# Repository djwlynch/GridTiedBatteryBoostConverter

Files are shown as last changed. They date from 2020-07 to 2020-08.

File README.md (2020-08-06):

# GridTiedBatteryBoostConverter

This is a project to build a device that will allow a 28 Cell 100AH LiFePo4 Battery Pack
to be connected to a generic MPPT Grid Tied Inverter via the solar DC input.
It will limit the power drawn from the battery pack to a maximum of 1000W.
This should allow a good base load for a typical 1st world house.
The LiFePo4 cell is 3.2V nominal voltage and 3.65V Max. 3.1V is fairly flat,so
this means the 28 cell battery pack voltage range should be 86.8V min 89.6V Nominal and 102.2V Max.
The majority of Grid tied inverters I have seen won't start until they get 150V DC from Pannels,
so this device will boost this voltage up to 160V.  It will include a current sense transformer and
isolating transformer to sample the house Voltage and current Draw, and thus be able to determine the
houses power consumption from the Grid.  It will be able to sense the power that it is supplying
to the Grid Tied inverter, and use this info to try to keep the house power from the Grid at about 0 Watts.
It will do this until it supplies a maximum of 1000W to the inverter, any higher than this and the grid
can supply it.  It will also have FETs for turning on and off a seperate charger.
The charger is 2000W 102.2V 20A. The CPU of the system is a Teensy_LC, with LCD, 3 buttons and a ESP_WROOM_02U
wifi module. The LCD is driven by an I2C bus the ESP has jumperable access to this bus also, and the I2C
bus is brought out to a header incase extra monitoring is required ie temperature or pressure etc.

The peak current mode control is based around the UCC2800 TI mosfet gate driver.

Warning I am not an electrical engineer and this may kill you / burn down your house,
all risks are your own.  I have not yet built this myself, but will update when I have.

<b>To install :</b>
change into your kicad projects directory and issue<br>
git clone https://github.com/djwlynch/GridTiedBatteryBoostConverter
Also in you kicad project directory issue the following<br>
git clone https://github.com/djwlynch/custom_kicad_library --recursive

the --recursive is important and it pulls down the required submodules for kicad librarys I have used,
namely teensy_library and teensy.pretty and digikey_kicad_library.

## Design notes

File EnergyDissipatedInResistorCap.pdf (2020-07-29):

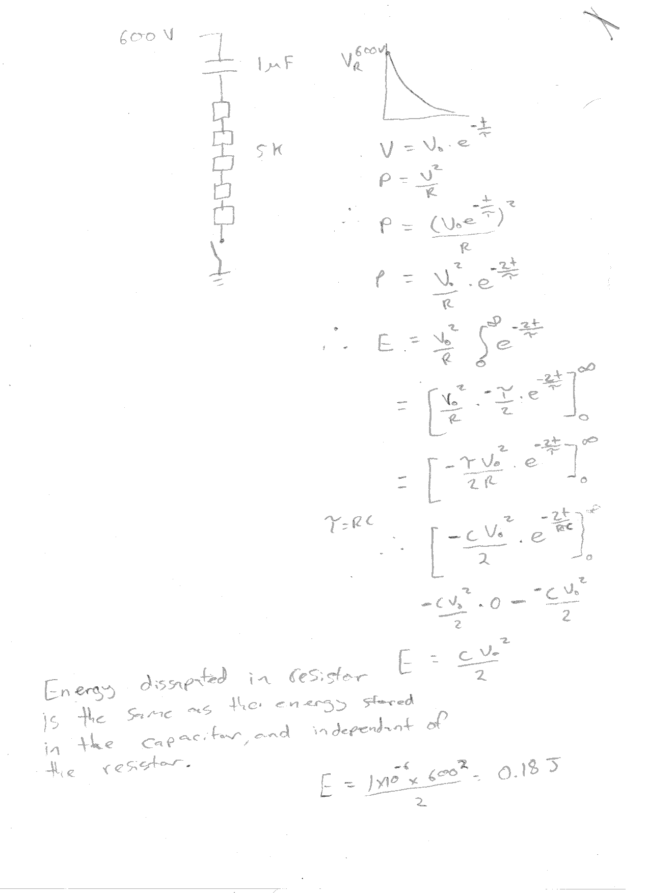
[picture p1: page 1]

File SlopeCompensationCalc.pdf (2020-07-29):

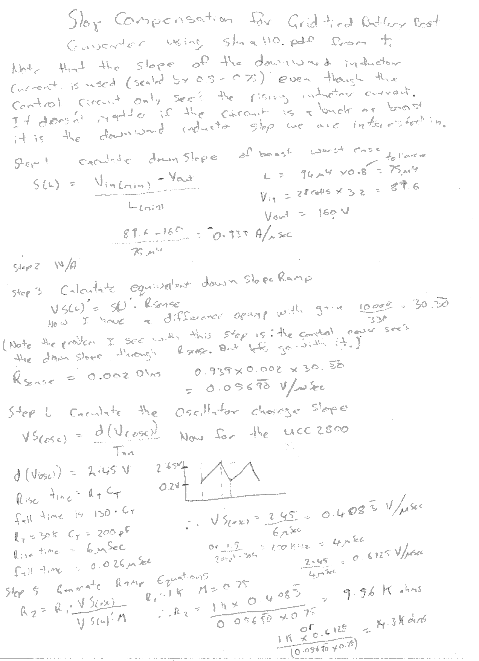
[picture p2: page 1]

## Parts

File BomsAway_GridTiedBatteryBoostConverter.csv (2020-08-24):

Refs | Value | Footprint | Quantity | MFR | MPN | SPR | SPN
SW202 | SW_Down | Buttons_Switches_ThroughHole_jl:SW_Tactile_SPST_Angled_FSM104 | 1 | TE Connectivity ALCOSWITCH Switches | FSM104 | digikey | 450-1127-ND
SW203 | SW_Enter | Buttons_Switches_ThroughHole_jl:SW_Tactile_SPST_Angled_FSM104 | 1 | TE Connectivity ALCOSWITCH Switches | FSM104 | digikey | 450-1127-ND
SW201 | SW_Up | Buttons_Switches_ThroughHole_jl:SW_Tactile_SPST_Angled_FSM104 | 1 | TE Connectivity ALCOSWITCH Switches | FSM104 | digikey | 450-1127-ND
C402;C403;C309;C312;C304;C109;C112;C107;C202;C203;C205 | 0.1uF X7R 25V 10% | Capacitor_SMD:C_0805_2012Metric_Pad1.15x1.40mm_HandSolder | 11 | Samsung | CL21B104KACNNNC | digikey | 1276-1099-1-ND
C302 | 0.47uF X7R 25V 10% | Capacitor_SMD:C_0805_2012Metric_Pad1.15x1.40mm_HandSolder | 1 | Samsung Electro-Mechanics | CL21B474KAFNNNE | digikey | 1276-1074-1-ND
Cint101 | 0.56uF X7R 16V 10% | Capacitor_SMD:C_0805_2012Metric_Pad1.15x1.40mm_HandSolder | 1 | KEMET | C0805C564K4RACTU | dikikey | 399-10074-1-ND
C105 | 100pF | Capacitor_SMD:C_0805_2012Metric_Pad1.15x1.40mm_HandSolder | 1 | KEMET | C0805C101JAGAC7800 | digikey | 399-15000-1-ND
C113 | 1nF | Capacitor_SMD:C_0805_2012Metric_Pad1.15x1.40mm_HandSolder | 1 | Yageo | CC0805KRX7R9BB102 | digikey | 311-1127-1-ND
C401;C313;C108;C114;C111;C106;C115;C201 | 1uF X7R 25V 10% | Capacitor_SMD:C_0805_2012Metric_Pad1.15x1.40mm_HandSolder | 8 | Wurth Elektronik | 885012207078 | digikey | 732-7672-1-ND
Ct101 | 200pF C0G 2% | Capacitor_SMD:C_0805_2012Metric_Pad1.15x1.40mm_HandSolder | 1 | AVX Corporation | 08051A201GAT2A | digikey | 478-10384-1-ND
Crolloff101 | 68pF C0G 5% | Capacitor_SMD:C_0805_2012Metric_Pad1.15x1.40mm_HandSolder | 1 | Wurth Elektronik | 885012007081 | digikey | 732-12227-1-ND
C110 | 6pF C0G | Capacitor_SMD:C_0805_2012Metric_Pad1.15x1.40mm_HandSolder | 1 | Yageo | CC0805CRNPO9BN6R0 | digikey | 311-4149-1-ND
C311;C310;C308;C307;C305;C301;C204 | 10uF X7R 25V 10% | Capacitor_SMD:C_1206_3216Metric_Pad1.42x1.75mm_HandSolder | 7 | Samsung Electro-Mechanics | CL31B106KAHNNNE | digikey | 1276-1804-1-ND
C306;C315 | 33uF X7R 16V 20% | Capacitor_SMD:C_1812_4532Metric_Pad1.30x3.40mm_HandSolder | 2 | TDK Corporation | C4532X7R1C336M250KC | digikey | 445-3924-1-ND
C303;C314 | 1uF X7R 250V 10% | Capacitor_SMD:C_2220_5650Metric_Pad1.97x5.40mm_HandSolder | 2 | TDK Corporation | C5750X7R2E105K230KA | digikey | 445-2304-1-ND
C101 | 220uF ALUM 200V 905 mOhm 20% | Capacitor_THT:CP_Radial_D22.0mm_P10.00mm_SnapIn | 1 | Cornell Dubilier Electronics (CDE) | SLP221M200A1P3 | digikey | 338-1478-ND
C103 | 470uF ALUM 400V 130mOhm 20% | Capacitor_THT:CP_Radial_D35.0mm_P10.00mm_SnapIn | 1 | KEMET | ELH477M400AT4AA | digikey | 399-6073-ND
C102 | 15uF PP 250VDC 3.9mOhm | Capacitors_ThroughHole_jl:C_Axial_44mm_24.5mm_P50mm | 1 | KEMET | C4GADUD5150AA1J | digikey | 399-13088-ND
C104 | 70uF PP Film 500V 2.1mOhm | Capacitors_ThroughHole_jl:C_RECT_4PIN_L42mm_W30mm_P37.5mm_P20.3mm | 1 | KEMET | C4AQLBW5700A3LK | digikey | 399-17006-ND
F301;F101 | Fuse Holder | Connect_jl:BellFuse_6.3mmX32mm_FC_102-22 | 2 | Bel Fuse Inc. | FC-102-22 | digikey | 507-1702-ND
U201 | LCD 2004A Right Angle Header 16 pin 2.54mm | Connect_jl:LCD2004_Pin_Header_Angled_1x16_Pitch2.54mm | 1 | Adam Tech | PH1RB-16-UA | digikey | 2057-PH1RB-16-UA-ND
J101 | Battery Connection | Connect_jl:PhoenixContact_1x4_P5mm | 1 | Phoenix Contact | 1935792 | digikey | 277-14426-ND
J103 | Solar Panels | Connect_jl:TerminalBlock_4way_P6.35mm_P9.5mm_Holes1.7mm | 1 | Phoenix Contact | 1017516 | digikey | 277-17506-ND
D301 | 1A 150V 0.7V SMA | Diode_SMD:D_SMA_Handsoldering | 1 | Diodes Incorporated | SBR1U150SA-13 | digikey | SBR1U150SA-13DICT-ND
D101 | 8A 200V 0.950V | Diodes_ThroughHole_jl:Diode_TO_220AC_Horizonal | 1 | Vishay Semiconductor Diodes Division | FES8DT-E3/45 | digikey | FES8DT-E3/45GI-ND
D501;D503;D502 | VS-20ETS12-M3 1200V 1V fwd@10A | Diodes_ThroughHole_jl:Diode_TO_220AC_Horizonal | 3 | Vishay Semiconductor Diodes Division | VS-20ETS12-M3 | digikey | VS-20ETS12-M3-ND
U203 | PCF8574ADWR | Housings_SOIC:SOIC-16W_7.5x10.3mm_Pitch1.27mm | 1 | Texas Instruments | PCF8574ADWR | digikey | 296-13105-1-ND
U102 | UCC2800DTR | Housings_SOIC:SOIC-8_3.9x4.9mm_Pitch1.27mm | 1 | Texas Instruments | UCC2800DTR | digikey | 296-39529-1-ND
L302;L303 | 15uH 730mA Sat | Inductors_jl:Inductor_1210_HandSoldering | 2 | Taiyo Yuden | CBC3225T150KR | digikey | 587-3066-1-ND
L301 | 150uH 610mA | Inductors_jl:Inductor_Bourns_PM3308 | 1 | Bourns Inc. | PM3308-151M-RC | digikey | PM3308-151M-RCCT-ND
L101;L102 | 47uH 31A Sat 6.38m Ohm | Inductors_jl:Inductor_Wurth_7443763540470 | 2 | Wurth Elektronik | 7443763540470 | digikey | 732-13644-ND
U101 | OPA2837IDGKR | Package_SO:VSSOP-8_3.0x3.0mm_P0.65mm | 1 | Texas Instruments | OPA2837IDGKR | digikey | 296-49464-1-ND
U402 | LMC7101BYM5-TR | Package_TO_SOT_SMD:SOT-23-5_HandSoldering | 1 | Microchip Technology | LMC7101BYM5-TR | digi-key | 576-2575-1-ND
U401 | MIC7211YM5-TR | Package_TO_SOT_SMD:SOT-23-5_HandSoldering | 1 | Microchip Technology | MIC7211YM5-TR | digi-key | 576-1318-1-ND
U304 | TLV70430DBVT | Package_TO_SOT_SMD:SOT-23-5_HandSoldering | 1 | Texas Instruments | TLV70430DBVT | digikey | 296-32419-1-ND
U303;U306 | TPS560200DBVR | Package_TO_SOT_SMD:SOT-23-5_HandSoldering | 2 | Texas Instruments | TPS560200DBVR | digikey | 296-38559-1-ND
D401;D402;D403;D103;D102;D104;D504 | BAT54S | Package_TO_SOT_SMD:SOT-23_Handsoldering | 7 | Toshiba Semiconductor and Storage | TBAT54S,LM | digikey | TBAT54SLMCT-ND
Q301;Q102 | BC847B-13-F | Package_TO_SOT_SMD:SOT-23_Handsoldering | 2 | Diodes Incorporated | BC847B-13-F | digikey | BC847B-13-FDICT-ND
Q302 | BC856B-13-F | Package_TO_SOT_SMD:SOT-23_Handsoldering | 1 | Diodes Incorporated | BC856B-13-F | digikey | BC856B-13-FDICT-ND
U305 | REF2925AIDBZT | Package_TO_SOT_SMD:SOT-23_Handsoldering | 1 | Texas Instruments | REF2925AIDBZT | digikey | 296-13482-1-ND
Q104;Q203 | SSM3J334R | Package_TO_SOT_SMD:SOT-23_Handsoldering | 2 | Toshiba Semiconductor and Storage | SSM3J334R,LF | digikey | SSM3J334RLFCT-ND
Q401;Q402;Q103;Q201;Q202 | SSM3K329R | Package_TO_SOT_SMD:SOT-23_Handsoldering | 5 | Toshiba Semiconductor and Storage | SSM3K329R,LF | digikey | SSM3K329RLFCT-ND
JP203 | BOOT_OPTION | Pin_Headers:Pin_Header_Straight_1x02_Pitch2.54mm | 1 | Sullins Connector Solutions | PREC002SAAN-RC | digikey | S1012EC-02-ND
JP202 | SCL_EN | Pin_Headers:Pin_Header_Straight_1x02_Pitch2.54mm | 1 | Sullins Connector Solutions | PREC002SAAN-RC | digikey | S1012EC-02-ND
JP201 | SDA_EN | Pin_Headers:Pin_Header_Straight_1x02_Pitch2.54mm | 1 | Sullins Connector Solutions | PREC002SAAN-RC | digikey | S1012EC-02-ND
J202 | Conn_01x03_Female | Pin_Headers:Pin_Header_Straight_1x03_Pitch2.54mm | 1 | Sullins Connector Solutions | PREC003SAAN-RC | digikey | S1012EC-03-ND
J203 | I2C_BUS | Pin_Headers:Pin_Header_Straight_1x04_Pitch2.54mm | 1 | Adam Tech | PH1-04-UA | digikey | 2057-PH1-04-UA-ND
RV201 | 5K | Potentiometers:Potentiometer_Trimmer_Bourns_3006P | 1 | Bourns Inc | 3006P-7-502LF | digikey | 3006P-7-502LF-ND
U204 | ESP-WROOM-02U | RF_Module_jl:MODULE_ESP-WROOM-02U | 1 | Espressif Systems | ESP-WROOM-02U | digikey | 1904-1022-1-ND
R101 | 0R Ohms | Resistor_SMD:R_0805_2012Metric_Pad1.15x1.40mm_HandSolder | 1 | Stackpole Electronics Inc | RMCF0805ZT0R00 | digikey | RMCF0805ZT0R00CT-ND
R412 | 1.15K 1% | Resistor_SMD:R_0805_2012Metric_Pad1.15x1.40mm_HandSolder | 1 | Yageo | RC0805FR-071K15L | digikey | 311-1.15KCRCT-ND
R407 | 1.27K 1% | Resistor_SMD:R_0805_2012Metric_Pad1.15x1.40mm_HandSolder | 1 | Yageo | RC0805FR-071K27L | digikey | 311-1.27KCRCT-ND
R104;Rint2;R122 | 1.5K 0.1% | Resistor_SMD:R_0805_2012Metric_Pad1.15x1.40mm_HandSolder | 3 | Panasonic Electronic Components | ERA-6AEB152V | digikey | P1.5KDACT-ND
R501;R502;R503;R504;R505;R205 | 100K 1% | Resistor_SMD:R_0805_2012Metric_Pad1.15x1.40mm_HandSolder | 6 | Yageo | RC0805FR-07100KL | digikey | 311-100KCRCT-ND
R206 | 100R 1% | Resistor_SMD:R_0805_2012Metric_Pad1.15x1.40mm_HandSolder | 1 | Yageo | RC0805FR-07100RL | digikey | 311-100CRCT-ND
R310;R121 | 105k 0.1% | Resistor_SMD:R_0805_2012Metric_Pad1.15x1.40mm_HandSolder | 2 | Panasonic Electronic Components | ERA-6AEB1053V | digikey | P105KDACT-ND
R110;R109;R117;R116 | 10K 0.1% | Resistor_SMD:R_0805_2012Metric_Pad1.15x1.40mm_HandSolder | 4 | Panasonic Electronic Components | ERA-6AEB103V | digikey | P10KDACT-ND
R113 | 10R 1% | Resistor_SMD:R_0805_2012Metric_Pad1.15x1.40mm_HandSolder | 1 | Yageo | RC0805FR-0710RL | digikey | 311-10.0CRCT-ND
R107;R207;R210;R209;R213 | 15K 1% | Resistor_SMD:R_0805_2012Metric_Pad1.15x1.40mm_HandSolder | 5 | TE Connectivity Passive Product | CRGCQ0805F15K | digikey | A129763CT-ND
R309 | 196K 0.1% | Resistor_SMD:R_0805_2012Metric_Pad1.15x1.40mm_HandSolder | 1 | Panasonic Electronic Components | ERA-6AEB1963V | digikey | P196KDACT-ND
R402;Rint1;R105 | 1K 0.1% | Resistor_SMD:R_0805_2012Metric_Pad1.15x1.40mm_HandSolder | 3 | Panasonic Electronic Components | ERA-6AEB102V | digikey | P1.0KDACT-ND
R405;R408;R406;R413;R409;R312;R301;R106;R108;R506;R201;R202;R203;R204 | 1K 1% | Resistor_SMD:R_0805_2012Metric_Pad1.15x1.40mm_HandSolder | 14 | Yageo | RC0805FR-071KL | digikey | 311-1.00KCRCT-ND
R410;R115 | 1M 1% | Resistor_SMD:R_0805_2012Metric_Pad1.15x1.40mm_HandSolder | 2 | Yageo | RC0805FR-071ML | digikey | 311-1.00MCRCT-ND
R311;R304 | 20K 0.1% | Resistor_SMD:R_0805_2012Metric_Pad1.15x1.40mm_HandSolder | 2 | Panasonic Electronic Components | ERA-6AEB203V | digikey | P20KDACT-ND
R308 | 226k 0.1% | Resistor_SMD:R_0805_2012Metric_Pad1.15x1.40mm_HandSolder | 1 | Panasonic Electronic Components | ERA-6AEB2263V | digikey | P226KDACT-ND
R403 | 240 0.1% | Resistor_SMD:R_0805_2012Metric_Pad1.15x1.40mm_HandSolder | 1 | Panasonic Electronic Components | ERA-6AEB241V | digikey | P240DACT-ND
Rt101 | 30K 0.1% | Resistor_SMD:R_0805_2012Metric_Pad1.15x1.40mm_HandSolder | 1 | Panasonic Electronic Components | ERA-6AEB303V | digikey | P30KDACT-ND
R111;R112;R118;R119 | 330R 0.1% | Resistor_SMD:R_0805_2012Metric_Pad1.15x1.40mm_HandSolder | 4 | Panasonic Electronic Components | ERA-6AEB331V | digikey | P330DACT-ND
R302 | 330R 1% | Resistor_SMD:R_0805_2012Metric_Pad1.15x1.40mm_HandSolder | 1 | TE Connectivity Passive Product | CRGCQ0805F330R | digikey | A129743CT-ND
R404 | 41.2 0.1% | Resistor_SMD:R_0805_2012Metric_Pad1.15x1.40mm_HandSolder | 1 | TE Connectivity Passive Product | 8-1625868-6 | digikey | A110410CT-ND
R211;R212;R208 | 4K7 1% | Resistor_SMD:R_0805_2012Metric_Pad1.15x1.40mm_HandSolder | 3 | Yageo | RC0805FR-074K7L | digikey | 311-4.70KCRCT-ND
R401 | 5.9K 0 .1% | Resistor_SMD:R_0805_2012Metric_Pad1.15x1.40mm_HandSolder | 1 | Panasonic Electronic Components | ERA-6AEB5901V | digikey | P5.9KDACT-ND
R303 | 61.9K 0.1% | Resistor_SMD:R_0805_2012Metric_Pad1.15x1.40mm_HandSolder | 1 | Panasonic Electronic Components | ERA-6AEB6192V | digikey | P61.9KDACT-ND
R103 | 75K 0.1% | Resistor_SMD:R_0805_2012Metric_Pad1.15x1.40mm_HandSolder | 1 | Panasonic Electronic Components | ERJ-PB6B7502V | digikey | P20808CT-ND
R102 | 82K 0.1% | Resistor_SMD:R_0805_2012Metric_Pad1.15x1.40mm_HandSolder | 1 | Panasonic Electronic Components | ERA-6AEB823V | digikey | P82KDACT-ND
R114;R120 | 2 mOhm Thick Film 1% 1W | Resistor_SMD:R_1210_3225Metric_Pad1.42x2.65mm_HandSolder | 2 | Rohm Semiconductor | PMR25HZPFV2L00 | digikey | RHM.002APCT-ND
U301 | FDA217 | SMD_Packages:DIP-8_SMD | 1 | IXYS Integrated Circuits Division | FDA217S | digikey | CLA408-ND
TP301 | TP +0.8V | TestPoint:TestPoint_Pad_3.0x3.0mm | 1 | - | - | - | -
TP304 | TP +11.0V | TestPoint:TestPoint_Pad_3.0x3.0mm | 1 | - | - | - | -
TP305 | TP +2.5V | TestPoint:TestPoint_Pad_3.0x3.0mm | 1 | - | - | - | -
TP307 | TP +3.0V | TestPoint:TestPoint_Pad_3.0x3.0mm | 1 | - | - | - | -
TP302;TP202 | TP +3.3V | TestPoint:TestPoint_Pad_3.0x3.0mm | 2 | - | - | - | -
TP303 | TP +5V | TestPoint:TestPoint_Pad_3.0x3.0mm | 1 | - | - | - | -
TP401 | TP 1.25V | TestPoint:TestPoint_Pad_3.0x3.0mm | 1 | - | - | - | -
TP403 | TP 1.395V | TestPoint:TestPoint_Pad_3.0x3.0mm | 1 | - | - | - | -
TP101 | TP 2.5V | TestPoint:TestPoint_Pad_3.0x3.0mm | 1 | - | - | - | -
TP203 | TP_Boost_On | TestPoint:TestPoint_Pad_3.0x3.0mm | 1 | - | - | - | -
TP306 | TP_Charger_On | TestPoint:TestPoint_Pad_3.0x3.0mm | 1 | - | - | - | -
TP103 | TP_DAC | TestPoint:TestPoint_Pad_3.0x3.0mm | 1 | - | - | - | -
TP201 | TP_LCD_On | TestPoint:TestPoint_Pad_3.0x3.0mm | 1 | - | - | - | -
TP402 | TP_Peak_Current | TestPoint:TestPoint_Pad_3.0x3.0mm | 1 | - | - | - | -
TP501 | TP_Solar_Voltage | TestPoint:TestPoint_Pad_3.0x3.0mm | 1 | - | - | - | -
TP102 | TP_UCC_5V_REF | TestPoint:TestPoint_Pad_3.0x3.0mm | 1 | - | - | - | -
TR401 | FS-10-110-C2 | Transformers_ThroughHole_jl:FS10-110-C2 | 1 | Triad Magnetics | FS10-110-C2 | digikey | 237-1578-ND
Q101 | IXFP36N20X3 | Transistors_ThroughHole_jl:TO-220_Horizontal_Offset_Drain | 1 | IXYS | IXFP36N20X3 | digikey | IXFP36N20X3-ND
Q305;Q306 | IRFP4321PBF | Transistors_ThroughHole_jl:TO-247-3_Horizontal_TabDown | 2 | Infineon Technologies | IRFP4321PBF | digikey | IRFP4321PBF-ND
J401;J402 | Screw_Terminal_01x02 | digikey-footprints:Term_Block_1x2_P5mm | 2 | Phoenix Contact | 1792863 | digikey | 277-2518-ND
U302 | LTC7138EMSE-PBF | ltc7138:LTC7138EMSE-PBF | 1 | Linear Technology/Analog Devices | LTC7138EMSE#PBF | digikey | LTC7138EMSE#PBF-ND
U202 | Teensy-LC | teensy:Teensy30_31_32_LC | 1 | SparkFun Electronics | DEV-13305 | digikey | 1568-1233-ND

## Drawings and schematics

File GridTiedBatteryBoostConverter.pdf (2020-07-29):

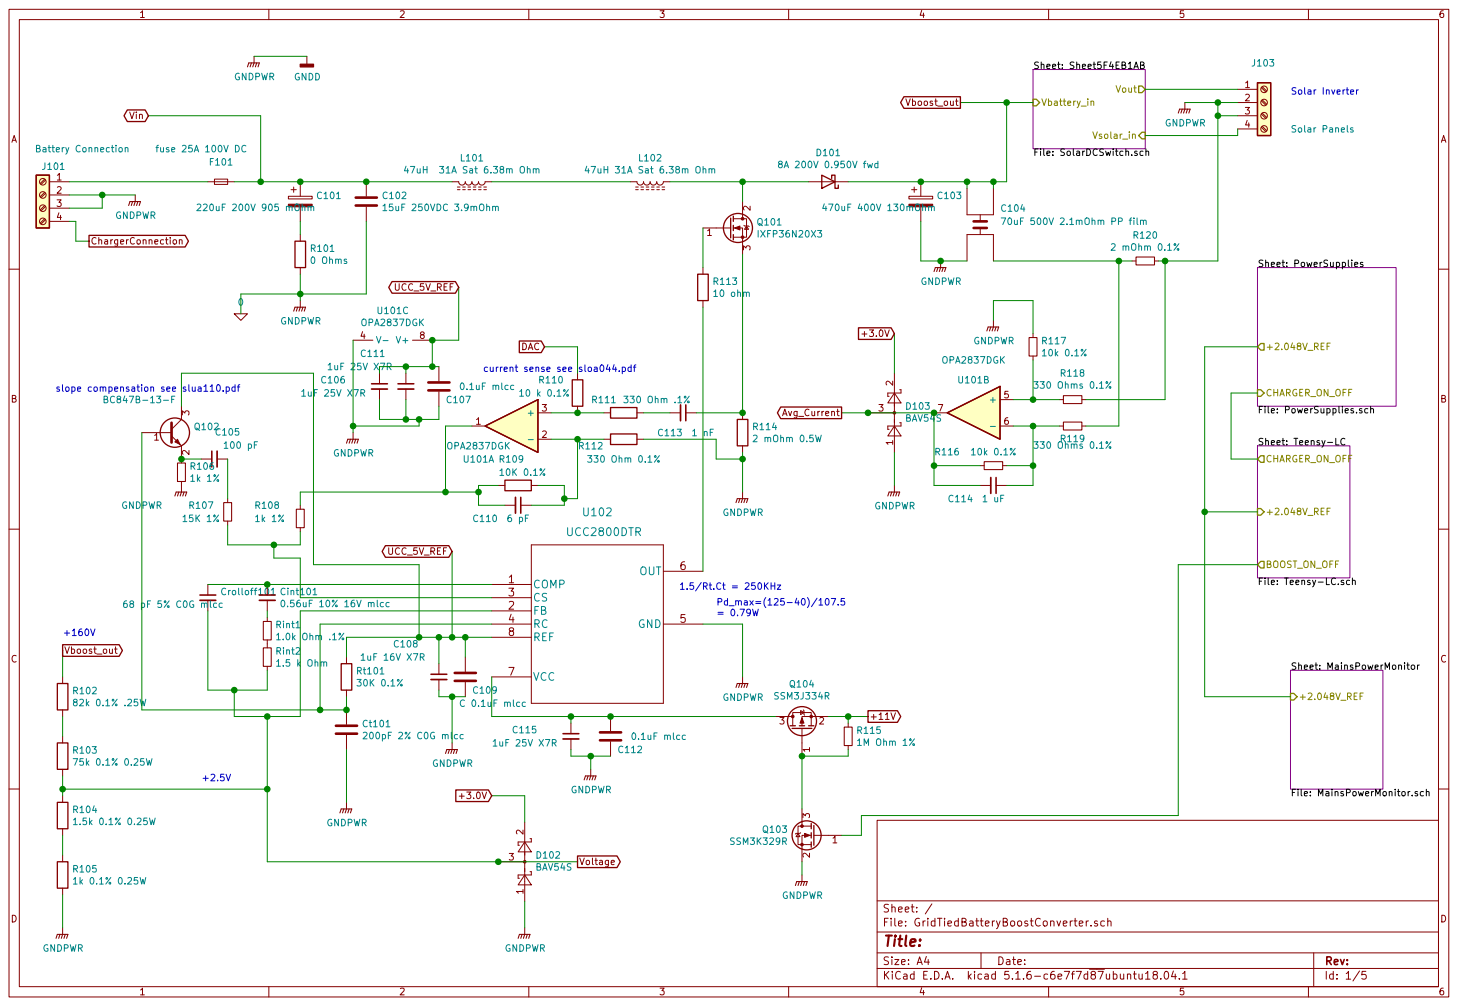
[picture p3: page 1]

File: SolarDCSwitch.sch Vsolar_in Vout Vbattery_in R112
IXFP36N20X3 GNDPWR

current sense see sloa044.pdf +160V

Sheet: Teensy-LC
File: Teensy-LC.sch CHARGER_ON_OFF BOOST_ON_OFF

File: GridTiedBatteryBoostConverter.sch Sheet: /
Id: 1/5 Title:

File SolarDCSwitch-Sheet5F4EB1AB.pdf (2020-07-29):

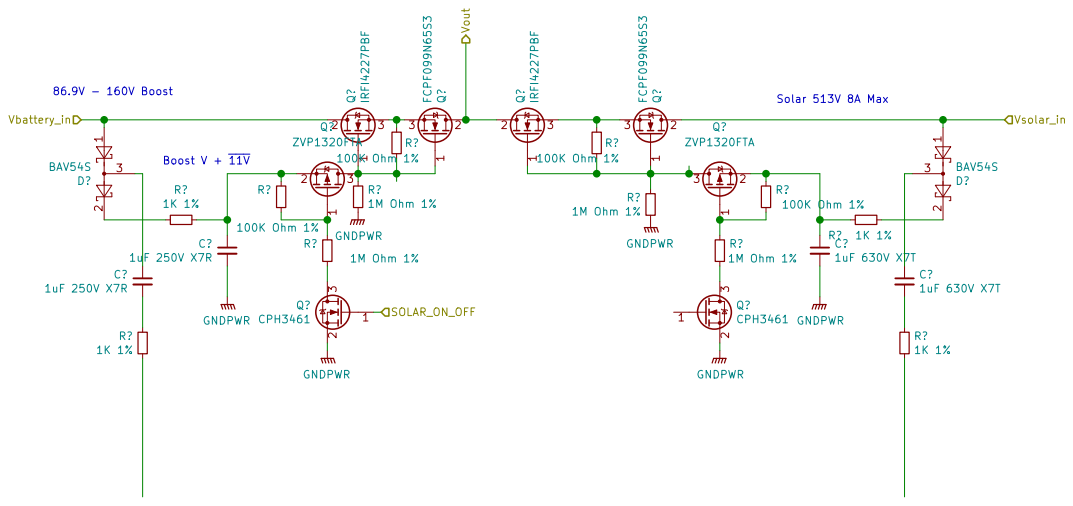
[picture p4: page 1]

Id: 5/5 Title: Battery / Solar Panel to Inverter Multiplexer File: SolarDCSwitch.sch Sheet: /Sheet5F4EB1AB/ John Lynch

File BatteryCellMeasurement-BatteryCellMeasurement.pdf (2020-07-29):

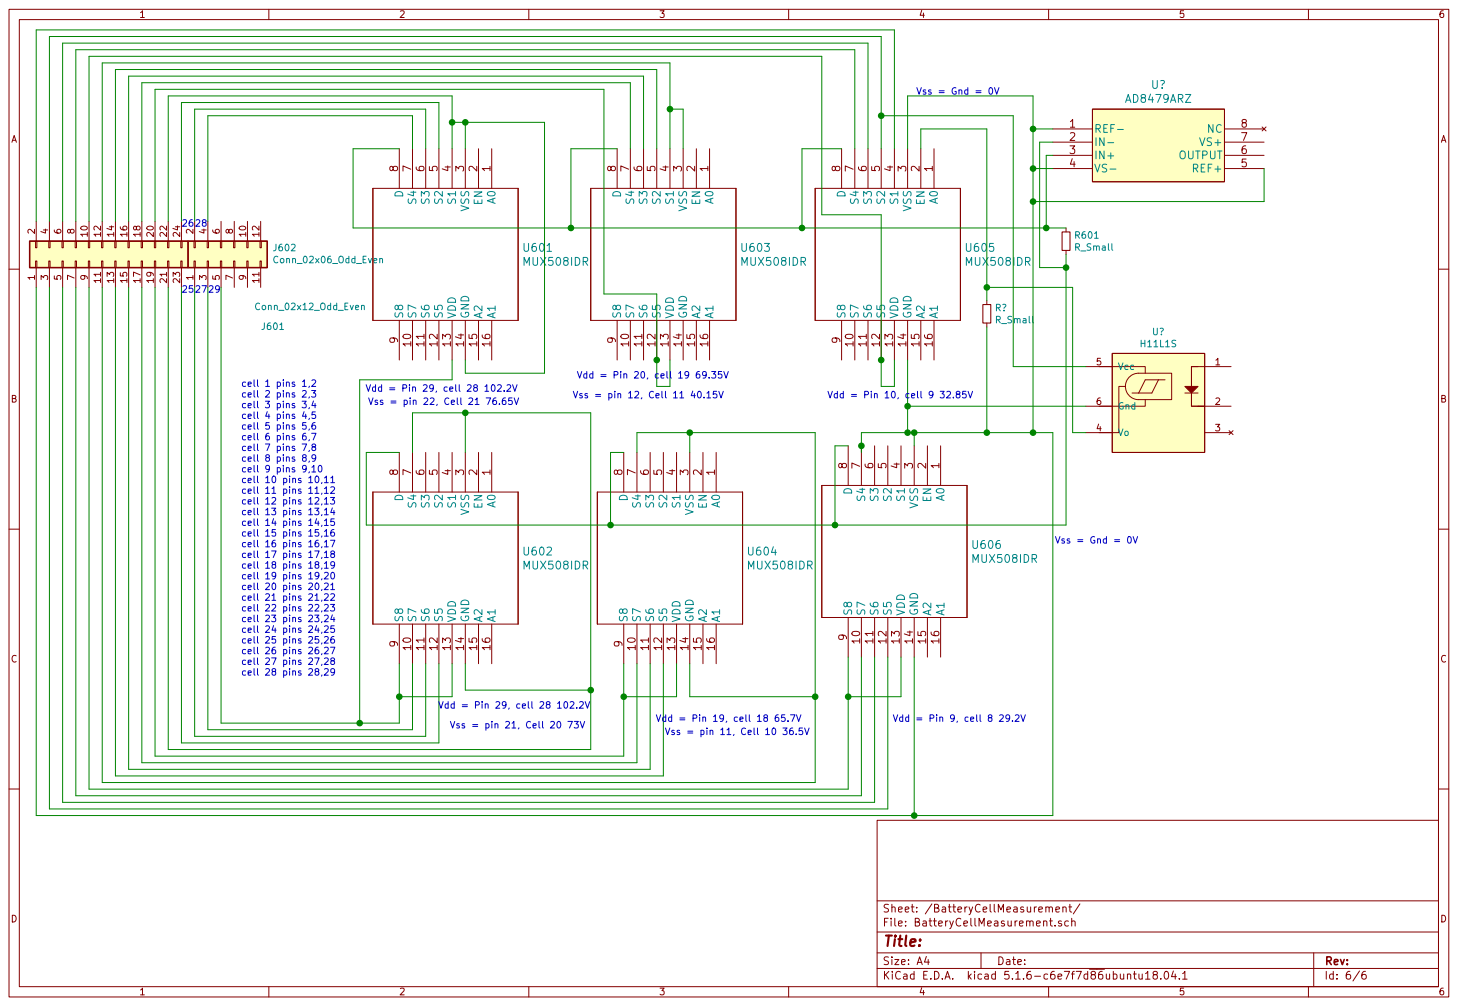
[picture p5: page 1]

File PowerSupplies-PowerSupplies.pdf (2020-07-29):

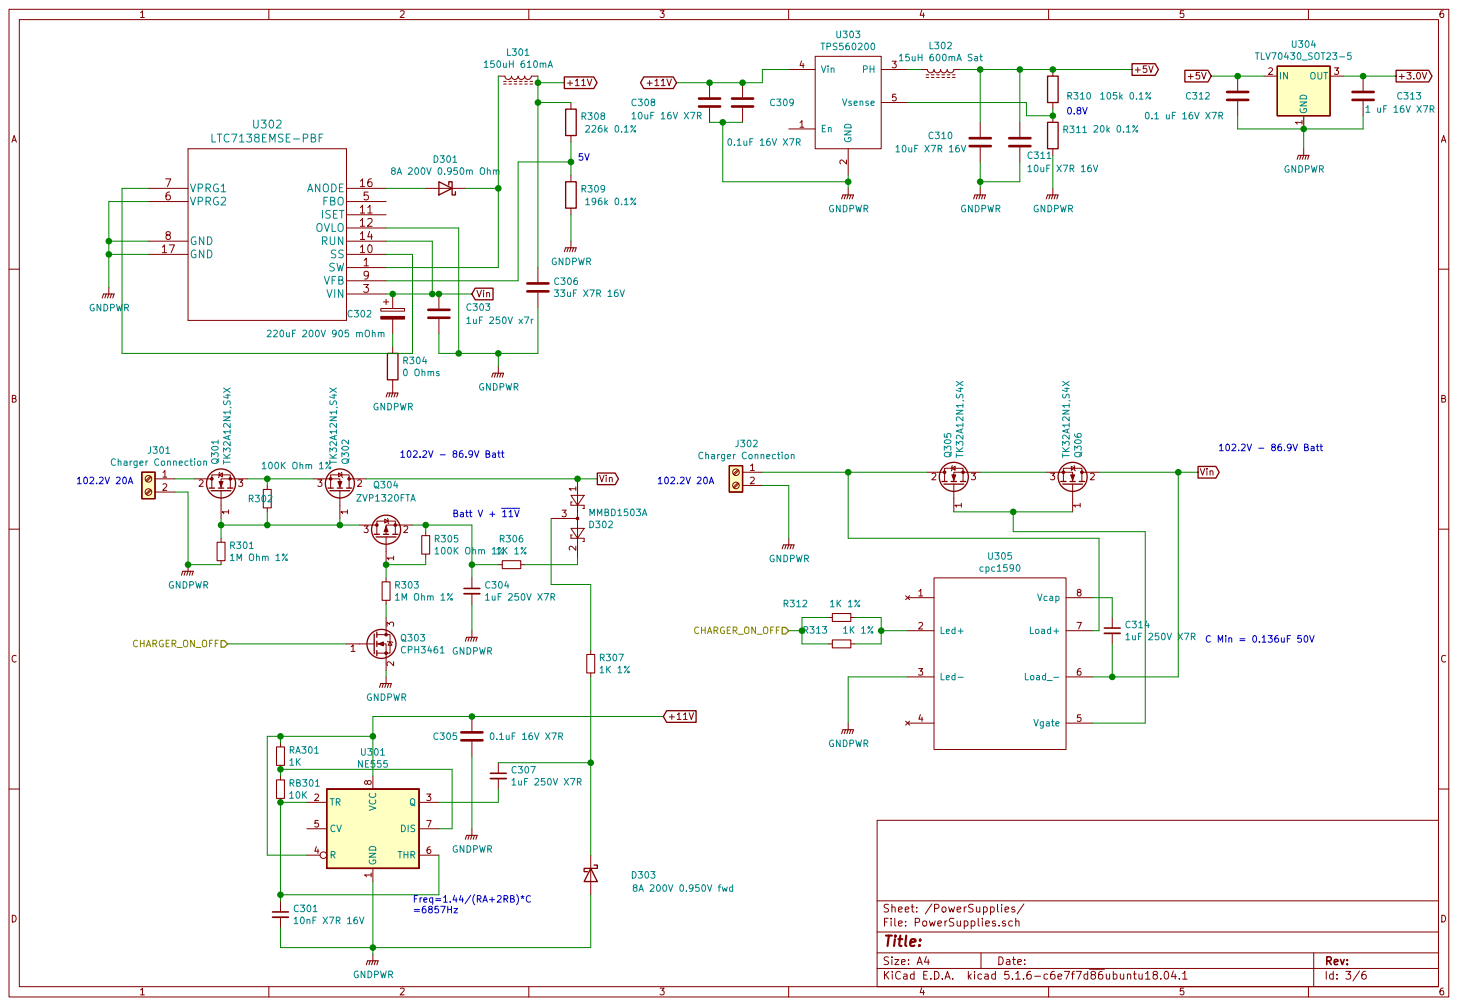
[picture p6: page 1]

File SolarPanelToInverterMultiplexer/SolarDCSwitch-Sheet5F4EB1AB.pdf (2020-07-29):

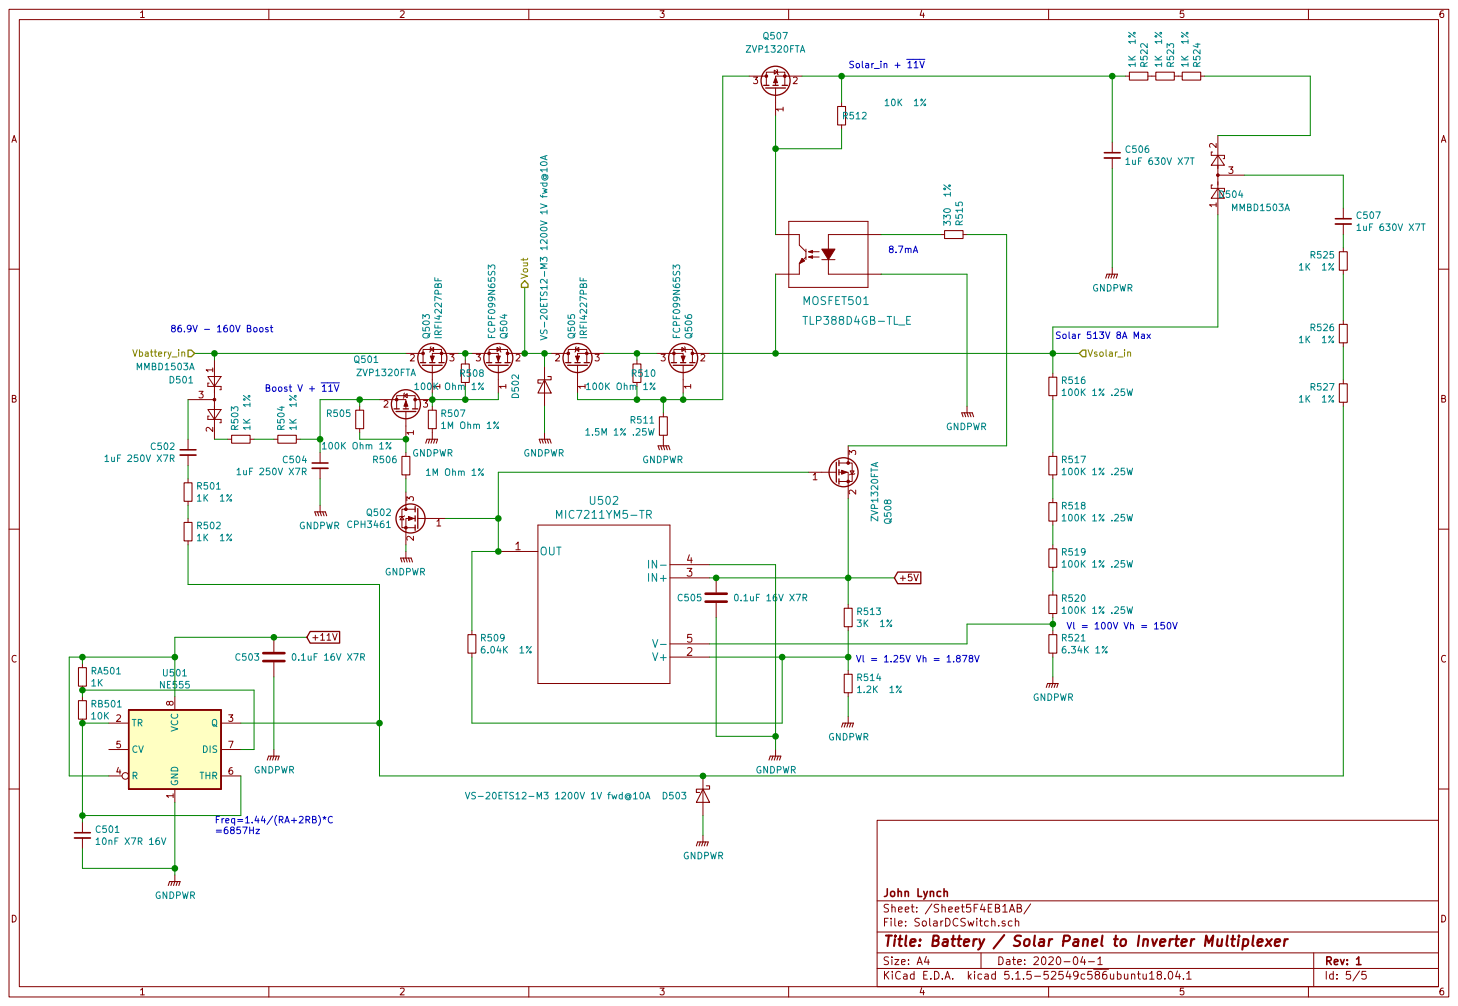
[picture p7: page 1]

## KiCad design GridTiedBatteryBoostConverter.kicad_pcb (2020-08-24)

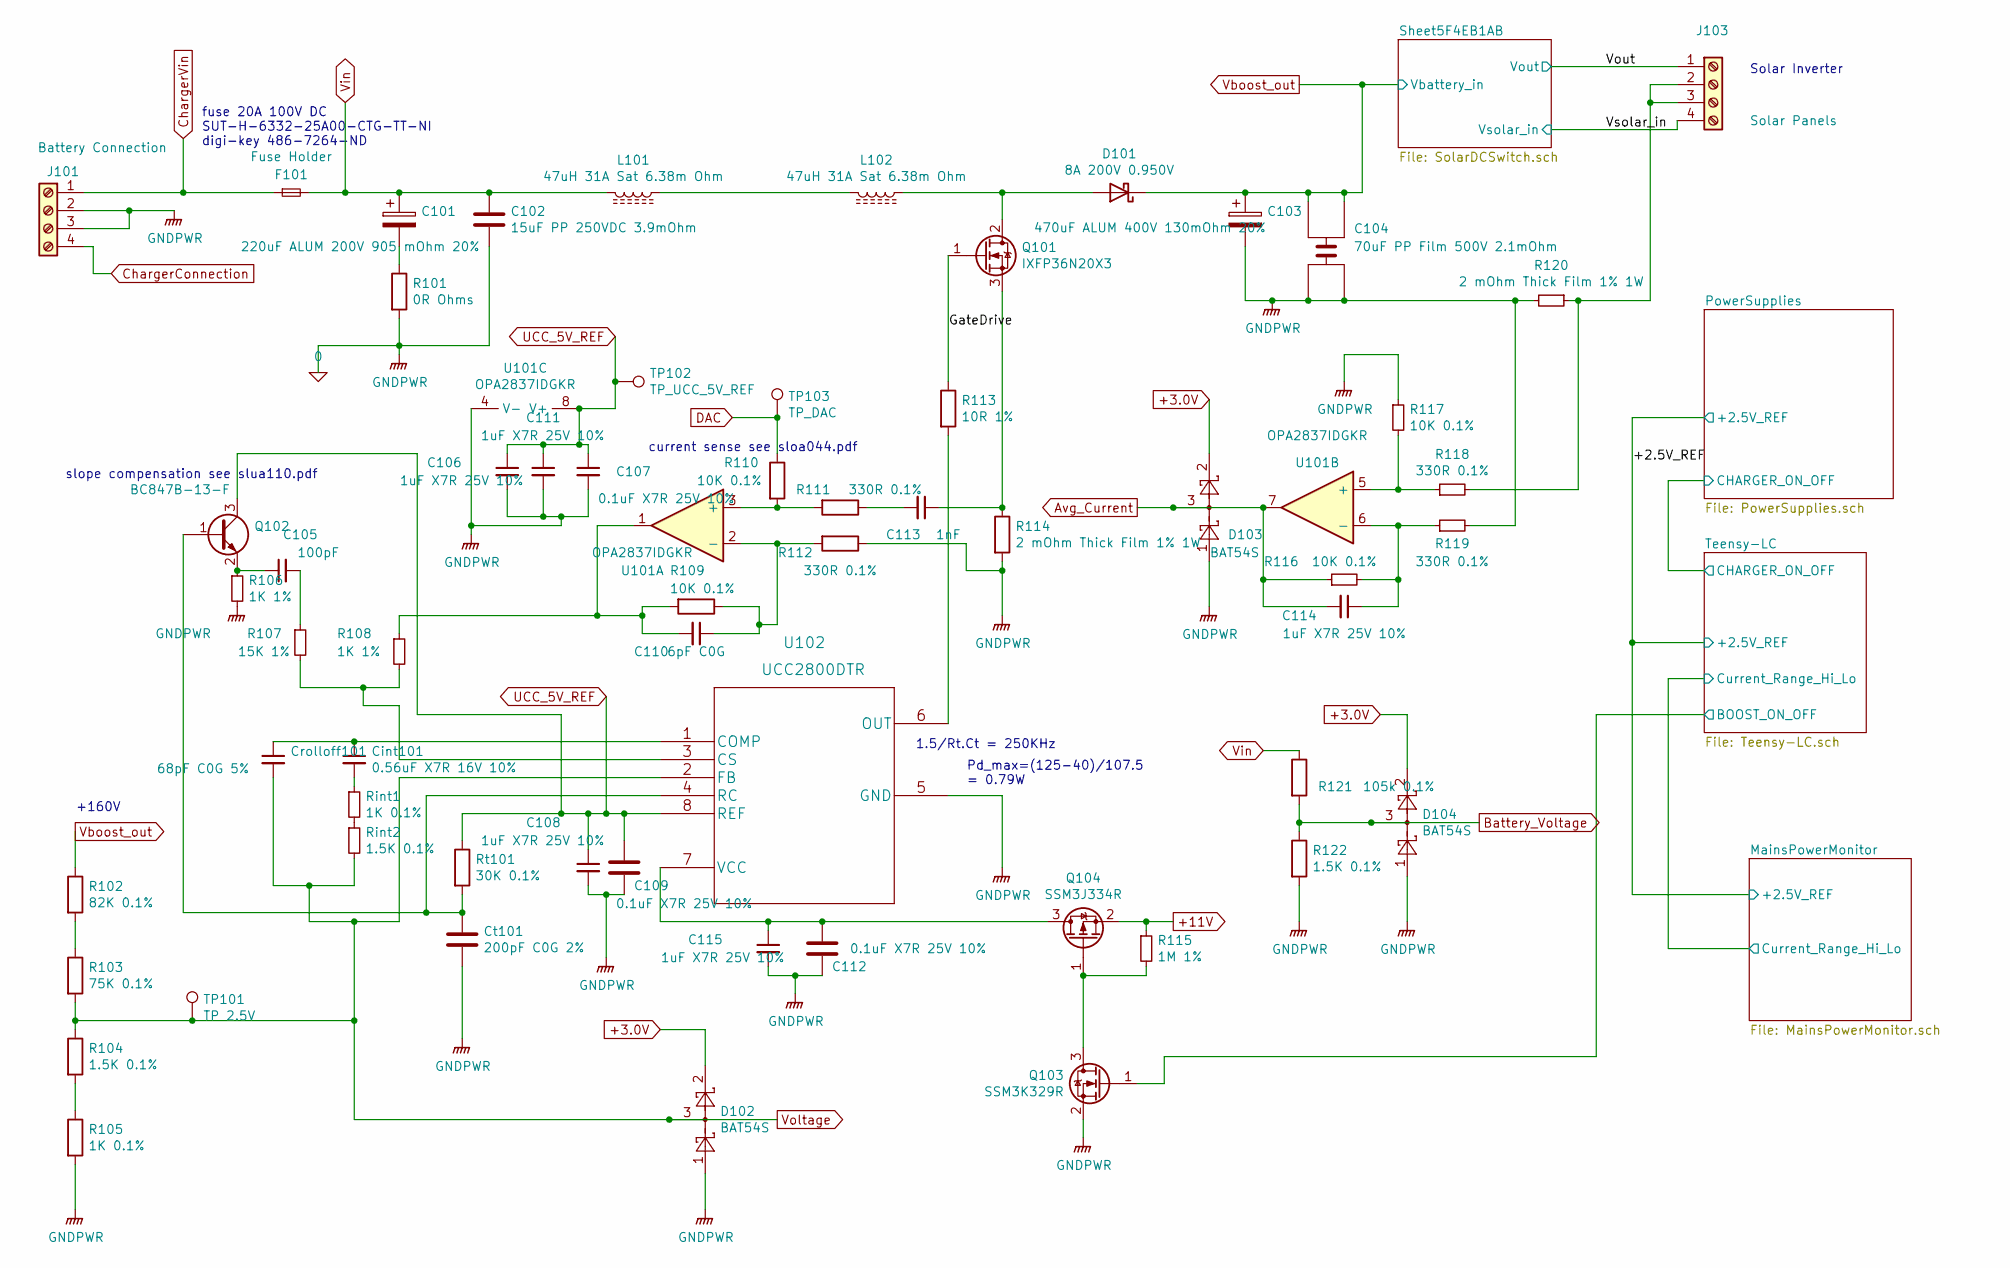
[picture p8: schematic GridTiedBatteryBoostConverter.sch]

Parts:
C101: 220uF ALUM 200V 905 mOhm 20%; CP_Radial_D22.0mm_P10.00mm_SnapIn; MPN SLP221M200A1P3
C102: 15uF PP 250VDC 3.9mOhm; C_Axial_44mm_24.5mm_P50mm; MPN C4GADUD5150AA1J
C103: 470uF ALUM 400V 130mOhm 20%; CP_Radial_D35.0mm_P10.00mm_SnapIn; MPN ELH477M400AT4AA
C104: 70uF PP Film 500V 2.1mOhm; C_RECT_4PIN_L42mm_W30mm_P37.5mm_P20.3mm; MPN C4AQLBW5700A3LK
C105: 100pF; C_0805_2012Metric_Pad1.15x1.40mm_HandSolder; MPN C0805C101JAGAC7800
C106, C108, C111, C114, C115: 1uF X7R 25V 10%; C_0805_2012Metric_Pad1.15x1.40mm_HandSolder; MPN 885012207078
C107, C109, C112: 0.1uF X7R 25V 10%; C_0805_2012Metric_Pad1.15x1.40mm_HandSolder; MPN CL21B104KACNNNC
C110: 6pF C0G; C_0805_2012Metric_Pad1.15x1.40mm_HandSolder; MPN CC0805CRNPO9BN6R0
C113: 1nF; C_0805_2012Metric_Pad1.15x1.40mm_HandSolder; MPN CC0805KRX7R9BB102
Cint101: 0.56uF X7R 16V 10%; C_0805_2012Metric_Pad1.15x1.40mm_HandSolder; MPN C0805C564K4RACTU
Crolloff101: 68pF C0G 5%; C_0805_2012Metric_Pad1.15x1.40mm_HandSolder; MPN 885012007081
Ct101: 200pF C0G 2%; C_0805_2012Metric_Pad1.15x1.40mm_HandSolder; MPN 08051A201GAT2A
D101: 8A 200V 0.950V; Diode_TO_220AC_Horizonal; MPN FES8DT-E3/45
D102, D103, D104: BAT54S; SOT-23_Handsoldering; MPN TBAT54S,LM
F101: Fuse Holder; BellFuse_6.3mmX32mm_FC_102-22; MPN FC-102-22
J101: Battery Connection; PhoenixContact_1x4_P5mm; MPN 1935792
J103: Solar Panels; TerminalBlock_4way_P6.35mm_P9.5mm_Holes1.7mm; MPN 1017516
L101, L102: 47uH 31A Sat 6.38m Ohm; Inductor_Wurth_7443763540470; MPN 7443763540470
Q101: IXFP36N20X3; TO-220_Horizontal_Offset_Drain; MPN IXFP36N20X3
Q102: BC847B-13-F; SOT-23_Handsoldering; MPN BC847B-13-F
Q103: SSM3K329R; SOT-23_Handsoldering; MPN SSM3K329R,LF
Q104: SSM3J334R; SOT-23_Handsoldering; MPN SSM3J334R,LF
R101: 0R Ohms; R_0805_2012Metric_Pad1.15x1.40mm_HandSolder; MPN RMCF0805ZT0R00
R102: 82K 0.1%; R_0805_2012Metric_Pad1.15x1.40mm_HandSolder; MPN ERA-6AEB823V
R103: 75K 0.1%; R_0805_2012Metric_Pad1.15x1.40mm_HandSolder; MPN ERJ-PB6B7502V
R104, R122: 1.5K 0.1%; R_0805_2012Metric_Pad1.15x1.40mm_HandSolder; MPN ERA-6AEB152V
R105: 1K 0.1%; R_0805_2012Metric_Pad1.15x1.40mm_HandSolder; MPN ERA-6AEB102V
R106, R108: 1K 1%; R_0805_2012Metric_Pad1.15x1.40mm_HandSolder; MPN RC0805FR-071KL
R107: 15K 1%; R_0805_2012Metric_Pad1.15x1.40mm_HandSolder; MPN CRGCQ0805F15K
R109, R110, R116, R117: 10K 0.1%; R_0805_2012Metric_Pad1.15x1.40mm_HandSolder; MPN ERA-6AEB103V
R111, R112, R118, R119: 330R 0.1%; R_0805_2012Metric_Pad1.15x1.40mm_HandSolder; MPN ERA-6AEB331V
R113: 10R 1%; R_0805_2012Metric_Pad1.15x1.40mm_HandSolder; MPN RC0805FR-0710RL
R114, R120: 2 mOhm Thick Film 1% 1W; R_1210_3225Metric_Pad1.42x2.65mm_HandSolder; MPN PMR25HZPFV2L00
R115: 1M 1%; R_0805_2012Metric_Pad1.15x1.40mm_HandSolder; MPN RC0805FR-071ML
R121: 105k 0.1%; R_0805_2012Metric_Pad1.15x1.40mm_HandSolder; MPN ERA-6AEB1053V
Rint1: 1K 0.1%; R_0805_2012Metric_Pad1.15x1.40mm_HandSolder; MPN ERA-6AEB102V
Rint2: 1.5K 0.1%; R_0805_2012Metric_Pad1.15x1.40mm_HandSolder; MPN ERA-6AEB152V
Rt101: 30K 0.1%; R_0805_2012Metric_Pad1.15x1.40mm_HandSolder; MPN ERA-6AEB303V
TP101: TP 2.5V; TestPoint_Pad_3.0x3.0mm
TP102: TP_UCC_5V_REF; TestPoint_Pad_3.0x3.0mm
TP103: TP_DAC; TestPoint_Pad_3.0x3.0mm
U101: OPA2837IDGKR; VSSOP-8_3.0x3.0mm_P0.65mm; MPN OPA2837IDGKR
U102: UCC2800DTR; SOIC-8_3.9x4.9mm_Pitch1.27mm; MPN UCC2800DTR

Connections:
0: C102.2, C103.2, C104.2, C104.3, C106.2, C107.2, C108.2, C109.2, C111.2, C112.2, C115.2, Ct101.2, D102.1, D103.1, D104.1, J101.2, J101.3, Q103.2 (S), R101.2, R105.2, R106.2, R112.1, R114.2, R117.1, R119.2, R120.2, R122.2, U101.4 (V-), U102.5 (GND); also elsewhere on the board
+3.0V: D102.2, D103.2, D104.2; also elsewhere on the board
+11V: Q104.2 (S), R115.1; also elsewhere on the board
/GateDrive: Q101.1 (G), R113.1
/Teensy-LC/BOOST_ON_OFF: Q103.1 (G); also elsewhere on the board
/Vout: J103.1; also elsewhere on the board
/Vsolar_in: J103.4; also elsewhere on the board
Avg_Current: C114.2, D103.3, R116.1, U101.7; also elsewhere on the board
Battery_Voltage: D104.3, R121.2, R122.1; also elsewhere on the board
ChargerConnection: J101.4; also elsewhere on the board
ChargerVin: F101.1, J101.1; also elsewhere on the board
DAC: R110.1, TP103.1; also elsewhere on the board
unnamed: C101.2, R101.1
unnamed: C105.1, Q102.2 (E), R106.1
unnamed: C105.2, R107.1
unnamed: C110.1, R109.1, R112.2, U101.2 (-)
unnamed: C110.2, R108.1, R109.2, U101.1
unnamed: C112.1, C115.1, Q104.3 (D), U102.7 (VCC)
unnamed: C113.1, Q101.3 (S), R114.1
unnamed: C113.2, R111.1
unnamed: C114.1, R116.2, R119.1, U101.6 (-)
unnamed: Cint101.1, Crolloff101.1, U102.1 (COMP)
unnamed: Cint101.2, Rint1.1
unnamed: Ct101.1, Q102.1 (B), Rt101.2, U102.4 (RC)
unnamed: D101.2 (A), L102.1, Q101.2 (D)
unnamed: J103.2, J103.3, R118.2, R120.1
unnamed: L101.1, L102.2
unnamed: Q103.3 (D), Q104.1 (G), R115.2
unnamed: R102.2, R103.1
unnamed: R104.2, R105.1
unnamed: R107.2, R108.2, U102.3 (CS)
unnamed: R110.2, R111.2, U101.3 (+)
unnamed: R113.2, U102.6 (OUT)
unnamed: R117.2, R118.1, U101.5 (+)
unnamed: Rint1.2, Rint2.1
UCC_5V_REF: C106.1, C107.1, C108.1, C109.1, C111.1, Q102.3 (C), Rt101.1, TP102.1, U101.8 (V+), U102.8 (REF)
Vboost_out: C103.1, C104.1, C104.4, D101.1 (K), R102.1; also elsewhere on the board
Vin: C101.1, C102.1, F101.2, L101.2, R121.1; also elsewhere on the board
Voltage: Crolloff101.2, D102.3, R103.2, R104.1, Rint2.2, TP101.1, U102.2 (FB); also elsewhere on the board

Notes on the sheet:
1.5/Rt.Ct = 250KHz
current sense see sloa044.pdf
slope compensation see slua110.pdf
Solar Inverter
Pd_max=(125-40)/107.5 = 0.79W
+160V
fuse 20A 100V DC SUT-H-6332-25A00-CTG-TT-NI digi-key 486-7264-ND

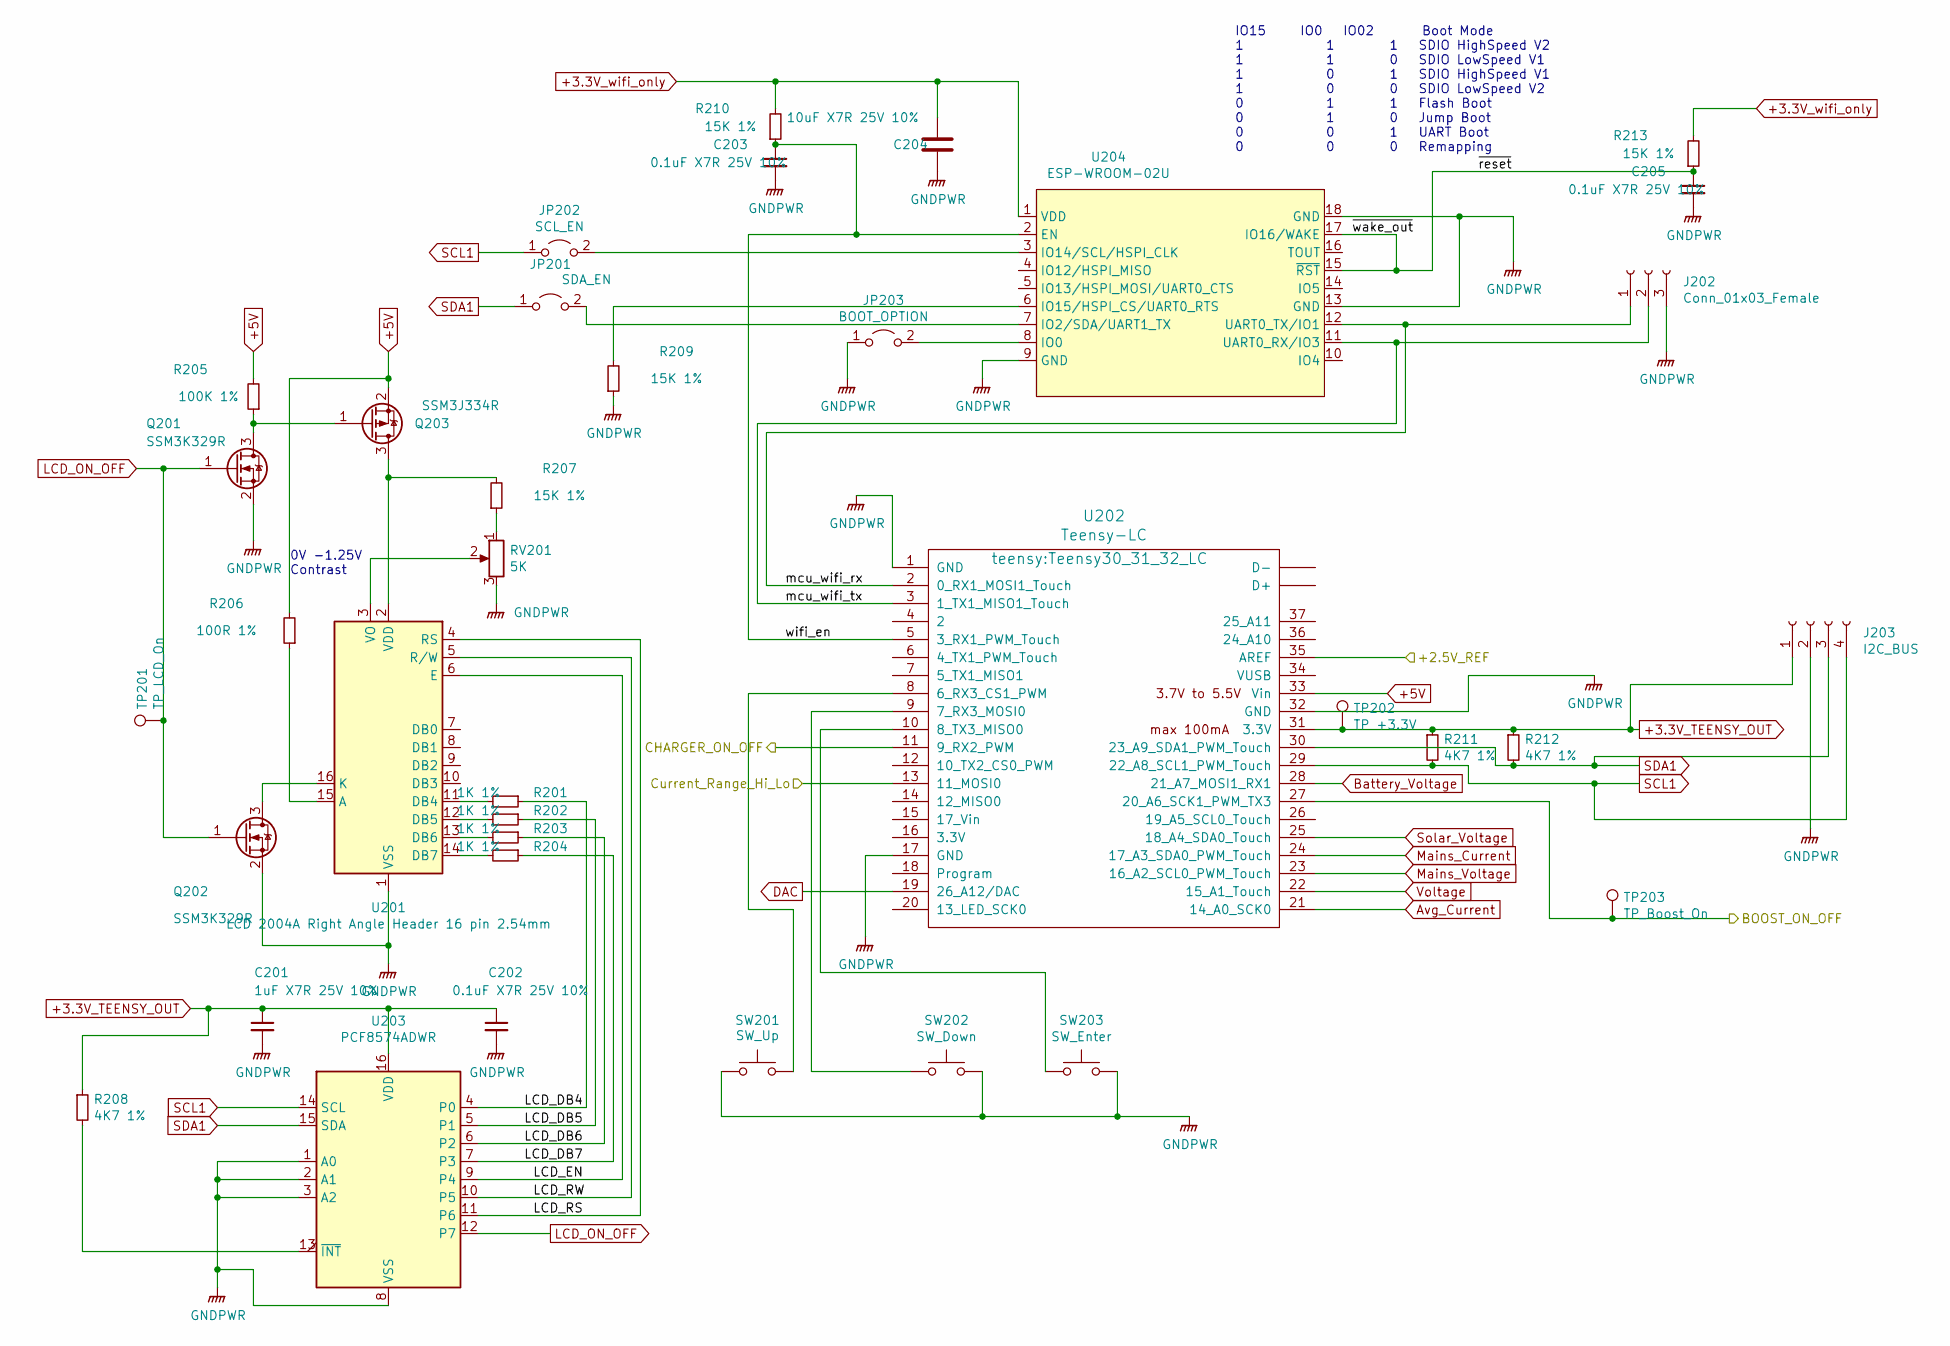
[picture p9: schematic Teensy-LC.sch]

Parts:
C201: 1uF X7R 25V 10%; C_0805_2012Metric_Pad1.15x1.40mm_HandSolder; MPN 885012207078
C202, C203, C205: 0.1uF X7R 25V 10%; C_0805_2012Metric_Pad1.15x1.40mm_HandSolder; MPN CL21B104KACNNNC
C204: 10uF X7R 25V 10%; C_1206_3216Metric_Pad1.42x1.75mm_HandSolder; MPN CL31B106KAHNNNE
J202: Conn_01x03_Female; Pin_Header_Straight_1x03_Pitch2.54mm; MPN PREC003SAAN-RC
J203: I2C_BUS; Pin_Header_Straight_1x04_Pitch2.54mm; MPN PH1-04-UA
JP201: SDA_EN; Pin_Header_Straight_1x02_Pitch2.54mm; MPN PREC002SAAN-RC
JP202: SCL_EN; Pin_Header_Straight_1x02_Pitch2.54mm; MPN PREC002SAAN-RC
JP203: BOOT_OPTION; Pin_Header_Straight_1x02_Pitch2.54mm; MPN PREC002SAAN-RC
Q201, Q202: SSM3K329R; SOT-23_Handsoldering; MPN SSM3K329R,LF
Q203: SSM3J334R; SOT-23_Handsoldering; MPN SSM3J334R,LF
R201, R202, R203, R204: 1K 1%; R_0805_2012Metric_Pad1.15x1.40mm_HandSolder; MPN RC0805FR-071KL
R205: 100K 1%; R_0805_2012Metric_Pad1.15x1.40mm_HandSolder; MPN RC0805FR-07100KL
R206: 100R 1%; R_0805_2012Metric_Pad1.15x1.40mm_HandSolder; MPN RC0805FR-07100RL
R207, R209, R210, R213: 15K 1%; R_0805_2012Metric_Pad1.15x1.40mm_HandSolder; MPN CRGCQ0805F15K
R208, R211, R212: 4K7 1%; R_0805_2012Metric_Pad1.15x1.40mm_HandSolder; MPN RC0805FR-074K7L
RV201: 5K; Potentiometer_Trimmer_Bourns_3006P; MPN 3006P-7-502LF
SW201: SW_Up; SW_Tactile_SPST_Angled_FSM104; MPN FSM104
SW202: SW_Down; SW_Tactile_SPST_Angled_FSM104; MPN FSM104
SW203: SW_Enter; SW_Tactile_SPST_Angled_FSM104; MPN FSM104
TP201: TP_LCD_On; TestPoint_Pad_3.0x3.0mm
TP202: TP +3.3V; TestPoint_Pad_3.0x3.0mm
TP203: TP_Boost_On; TestPoint_Pad_3.0x3.0mm
U201: LCD 2004A Right Angle Header 16 pin 2.54mm; LCD2004_Pin_Header_Angled_1x16_Pitch2.54mm; MPN PH1RB-16-UA
U202: Teensy-LC; Teensy30_31_32_LC; MPN DEV-13305
U203: PCF8574ADWR; SOIC-16W_7.5x10.3mm_Pitch1.27mm; MPN PCF8574ADWR
U204: ESP-WROOM-02U; MODULE_ESP-WROOM-02U; MPN ESP-WROOM-02U

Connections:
0: C201.2, C202.2, C203.2, C204.2, C205.2, J202.3, J203.2, JP203.1 (A), Q201.2 (S), Q202.2 (S), R209.1, RV201.3, SW201.1, SW202.2, SW203.2, U201.1 (VSS), U202.1 (GND), U202.17 (GND), U202.32 (GND), U203.1 (A0), U203.2 (A1), U203.3 (A2), U203.8 (VSS), U204.9 (GND), U204.13 (GND), U204.18 (GND), U204.19 (GND); also elsewhere on the board
+3.3V_TEENSY_OUT: C201.1, C202.1, J203.1, R208.1, R211.1, R212.1, TP202.1, U202.31 (3.3V), U203.16 (VDD)
+3.3V_wifi_only: C204.1, R210.2, R213.2, U204.1 (VDD); also elsewhere on the board
+5V: Q203.2 (S), R205.2, R206.2, U202.33 (Vin); also elsewhere on the board
/+2.5V_REF: U202.35 (AREF); also elsewhere on the board
/MainsPowerMonitor/Current_Range_Hi_Lo: U202.13 (11_MOSI0); also elsewhere on the board
/PowerSupplies/CHARGER_ON_OFF: U202.11 (9_RX2_PWM); also elsewhere on the board
/Teensy-LC/BOOST_ON_OFF: TP203.1, U202.27 (20_A6_SCK1_PWM_TX3); also elsewhere on the board
/Teensy-LC/LCD_DB4: R201.1, U203.4 (P0)
/Teensy-LC/LCD_DB5: R202.1, U203.5 (P1)
/Teensy-LC/LCD_DB6: R203.1, U203.6 (P2)
/Teensy-LC/LCD_DB7: R204.1, U203.7 (P3)
/Teensy-LC/LCD_EN: U201.6 (E), U203.9 (P4)
/Teensy-LC/LCD_RS: U201.4 (RS), U203.11 (P6)
/Teensy-LC/LCD_RW: U201.5 (R/W), U203.10 (P5)
/Teensy-LC/mcu_wifi_rx: J202.1, U202.2 (0_RX1_MOSI1_Touch), U204.12 (UART0_TX/IO1)
/Teensy-LC/mcu_wifi_tx: J202.2, U202.3 (1_TX1_MISO1_Touch), U204.11 (UART0_RX/IO3)
/Teensy-LC/wifi_en: C203.1, R210.1, U202.5 (3_RX1_PWM_Touch), U204.2 (EN)
/Teensy-LC/~reset: C205.1, R213.1, U204.15 (~RST), U204.17 (IO16/WAKE)
Avg_Current: U202.21 (14_A0_SCK0); also elsewhere on the board
Battery_Voltage: U202.28 (21_A7_MOSI1_RX1); also elsewhere on the board
DAC: U202.19 (26_A12/DAC); also elsewhere on the board
LCD_ON_OFF: Q201.1 (G), Q202.1 (G), TP201.1, U203.12 (P7)
Mains_Current: U202.24 (17_A3_SDA0_PWM_Touch); also elsewhere on the board
Mains_Voltage: U202.23 (16_A2_SCL0_PWM_Touch); also elsewhere on the board
unnamed: JP201.2 (B), U204.7 (IO2/SDA/UART1_TX)
unnamed: JP202.2 (B), U204.3 (IO14/SCL/HSPI_CLK)
unnamed: JP203.2 (B), U204.8 (IO0)
unnamed: Q201.3 (D), Q203.1 (G), R205.1
unnamed: Q202.3 (D), U201.16 (K)
unnamed: Q203.3 (D), R207.2, U201.2 (VDD)
unnamed: R201.2, U201.11 (DB4)
unnamed: R202.2, U201.12 (DB5)
unnamed: R203.2, U201.13 (DB6)
unnamed: R204.2, U201.14 (DB7)
unnamed: R206.1, U201.15 (A)
unnamed: R207.1, RV201.1
unnamed: R208.2, U203.13 (~INT~)
unnamed: R209.2, U204.6 (IO15/HSPI_CS/UART0_RTS)
unnamed: RV201.2, U201.3 (VO)
unnamed: SW201.2, U202.8 (6_RX3_CS1_PWM)
unnamed: SW202.1, U202.9 (7_RX3_MOSI0)
unnamed: SW203.1, U202.10 (8_TX3_MISO0)
SCL1: J203.4, JP202.1 (A), R211.2, U202.29 (22_A8_SCL1_PWM_Touch), U203.14 (SCL)
SDA1: J203.3, JP201.1 (A), R212.2, U202.30 (23_A9_SDA1_PWM_Touch), U203.15 (SDA)
Solar_Voltage: U202.25 (18_A4_SDA0_Touch); also elsewhere on the board
Voltage: U202.22 (15_A1_Touch); also elsewhere on the board

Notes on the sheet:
0V -1.25V Contrast
IO15 IO0 IO02 Boot Mode 1 1 1 SDIO HighSpeed V2 1 1 0 SDIO LowSpeed V1 1 0 1 SDIO HighSpeed V1 1 0 0 SDIO LowSpeed V2 0 1 1 Flash Boot 0 1 0 Jump Boot 0 0 1 UART Boot 0 0 0 Remapping

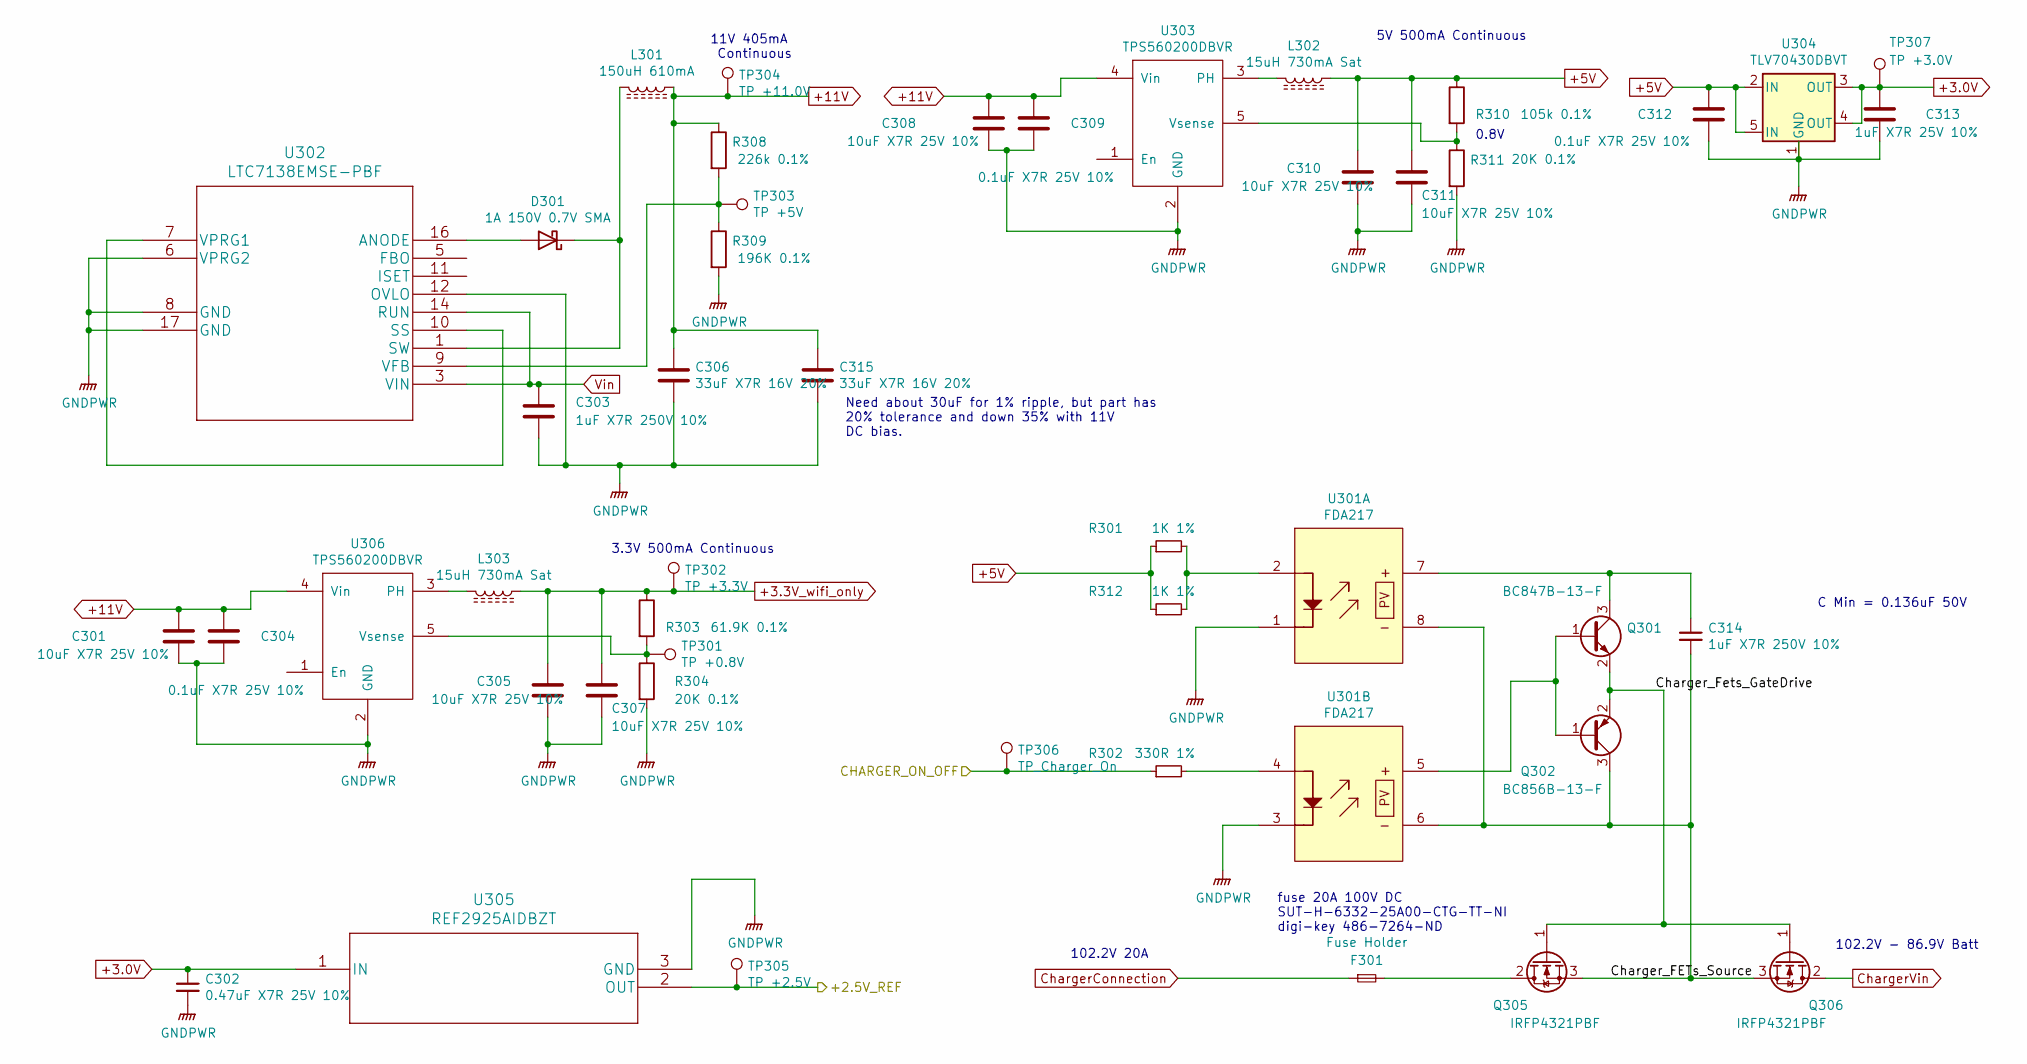
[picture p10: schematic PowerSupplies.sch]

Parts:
C301, C305, C307, C308, C310, C311: 10uF X7R 25V 10%; C_1206_3216Metric_Pad1.42x1.75mm_HandSolder; MPN CL31B106KAHNNNE
C302: 0.47uF X7R 25V 10%; C_0805_2012Metric_Pad1.15x1.40mm_HandSolder; MPN CL21B474KAFNNNE
C303, C314: 1uF X7R 250V 10%; C_2220_5650Metric_Pad1.97x5.40mm_HandSolder; MPN C5750X7R2E105K230KA
C304, C309, C312: 0.1uF X7R 25V 10%; C_0805_2012Metric_Pad1.15x1.40mm_HandSolder; MPN CL21B104KACNNNC
C306, C315: 33uF X7R 16V 20%; C_1812_4532Metric_Pad1.30x3.40mm_HandSolder; MPN C4532X7R1C336M250KC
C313: 1uF X7R 25V 10%; C_0805_2012Metric_Pad1.15x1.40mm_HandSolder; MPN 885012207078
D301: 1A 150V 0.7V SMA; D_SMA_Handsoldering; MPN SBR1U150SA-13
F301: Fuse Holder; BellFuse_6.3mmX32mm_FC_102-22; MPN FC-102-22
L301: 150uH 610mA; Inductor_Bourns_PM3308; MPN PM3308-151M-RC
L302, L303: 15uH 730mA Sat; Inductor_1210_HandSoldering; MPN CBC3225T150KR
Q301: BC847B-13-F; SOT-23_Handsoldering; MPN BC847B-13-F
Q302: BC856B-13-F; SOT-23_Handsoldering; MPN BC856B-13-F
Q305, Q306: IRFP4321PBF; TO-247-3_Horizontal_TabDown; MPN IRFP4321PBF
R301, R312: 1K 1%; R_0805_2012Metric_Pad1.15x1.40mm_HandSolder; MPN RC0805FR-071KL
R302: 330R 1%; R_0805_2012Metric_Pad1.15x1.40mm_HandSolder; MPN CRGCQ0805F330R
R303: 61.9K 0.1%; R_0805_2012Metric_Pad1.15x1.40mm_HandSolder; MPN ERA-6AEB6192V
R304, R311: 20K 0.1%; R_0805_2012Metric_Pad1.15x1.40mm_HandSolder; MPN ERA-6AEB203V
R308: 226k 0.1%; R_0805_2012Metric_Pad1.15x1.40mm_HandSolder; MPN ERA-6AEB2263V
R309: 196K 0.1%; R_0805_2012Metric_Pad1.15x1.40mm_HandSolder; MPN ERA-6AEB1963V
R310: 105k 0.1%; R_0805_2012Metric_Pad1.15x1.40mm_HandSolder; MPN ERA-6AEB1053V
TP301: TP +0.8V; TestPoint_Pad_3.0x3.0mm
TP302: TP +3.3V; TestPoint_Pad_3.0x3.0mm
TP303: TP +5V; TestPoint_Pad_3.0x3.0mm
TP304: TP +11.0V; TestPoint_Pad_3.0x3.0mm
TP305: TP +2.5V; TestPoint_Pad_3.0x3.0mm
TP306: TP_Charger_On; TestPoint_Pad_3.0x3.0mm
TP307: TP +3.0V; TestPoint_Pad_3.0x3.0mm
U301: FDA217; DIP-8_SMD; MPN FDA217S
U302: LTC7138EMSE-PBF; MPN LTC7138EMSE#PBF
U303, U306: TPS560200DBVR; SOT-23-5_HandSoldering; MPN TPS560200DBVR
U304: TLV70430DBVT; SOT-23-5_HandSoldering; MPN TLV70430DBVT
U305: REF2925AIDBZT; SOT-23_Handsoldering; MPN REF2925AIDBZT

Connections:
0: C301.2, C302.2, C303.2, C304.2, C305.2, C306.2, C307.2, C308.2, C309.2, C310.2, C311.2, C312.2, C313.2, C315.2, R304.2, R309.2, R311.2, U301.1, U301.3, U302.6 (VPRG2), U302.8 (GND), U302.12 (OVLO), U302.17 (GND), U303.2 (GND), U304.1 (GND), U305.3 (GND), U306.2 (GND); also elsewhere on the board
+3.0V: C302.1, C313.1, TP307.1, U304.3 (OUT), U304.4 (OUT), U305.1 (IN); also elsewhere on the board
+3.3V_wifi_only: C305.1, C307.1, L303.1, R303.1, TP302.1; also elsewhere on the board
+5V: C310.1, C311.1, C312.1, L302.1, R301.1, R310.1, R312.1, U304.2 (IN), U304.5 (IN); also elsewhere on the board
+11V: C301.1, C304.1, C306.1, C308.1, C309.1, C315.1, L301.1, R308.1, TP304.1, U303.4 (Vin), U306.4 (Vin); also elsewhere on the board
/+2.5V_REF: TP305.1, U305.2 (OUT); also elsewhere on the board
/PowerSupplies/CHARGER_ON_OFF: R302.1, TP306.1; also elsewhere on the board
/PowerSupplies/Charger_FETs_Source: C314.2, Q302.3 (C), Q305.3 (S), Q306.3 (S), U301.6, U301.8
/PowerSupplies/Charger_Fets_GateDrive: Q301.2 (E), Q302.2 (E), Q305.1 (G), Q306.1 (G)
ChargerConnection: F301.1; also elsewhere on the board
ChargerVin: Q306.2 (D); also elsewhere on the board
unnamed: C314.1, Q301.3 (C), U301.7
unnamed: D301.1 (K), L301.2, U302.1 (SW)
unnamed: D301.2 (A), U302.16 (ANODE)
unnamed: F301.2, Q305.2 (D)
unnamed: L302.2, U303.3 (PH)
unnamed: L303.2, U306.3 (PH)
unnamed: Q301.1 (B), Q302.1 (B), U301.5
unnamed: R301.2, R312.2, U301.2
unnamed: R302.2, U301.4
unnamed: R303.2, R304.1, TP301.1, U306.5 (Vsense)
unnamed: R308.2, R309.1, TP303.1, U302.9 (VFB)
unnamed: R310.2, R311.1, U303.5 (Vsense)
unnamed: U302.7 (VPRG1), U302.10 (SS)
Vin: C303.1, U302.3 (VIN), U302.14 (RUN); also elsewhere on the board

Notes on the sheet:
0.8V
C Min = 0.136uF 50V
102.2V - 86.9V Batt
102.2V 20A
11V 405mA Continuous
5V 500mA Continuous
3.3V 500mA Continuous
Need about 30uF for 1% ripple, but part has 20% tolerance and down 35% with 11V DC bias.
fuse 20A 100V DC SUT-H-6332-25A00-CTG-TT-NI digi-key 486-7264-ND

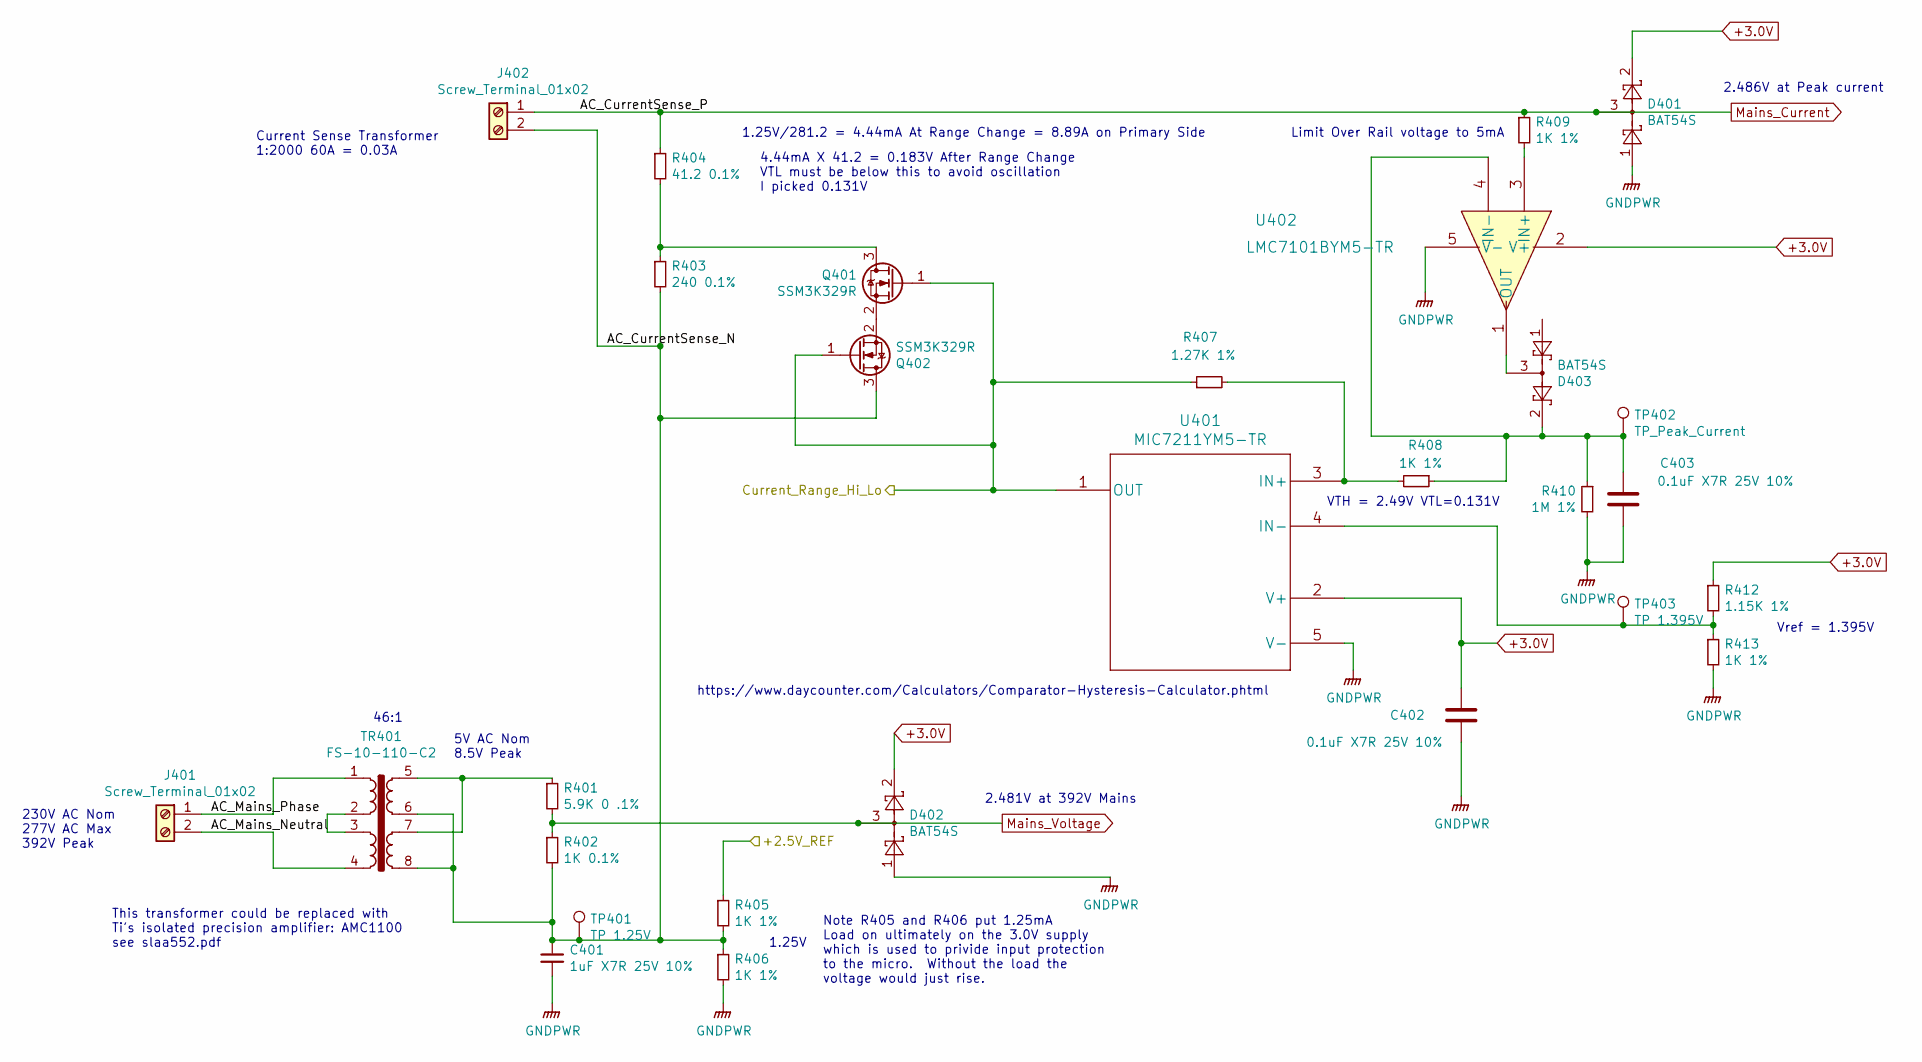
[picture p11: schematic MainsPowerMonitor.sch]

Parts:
C401: 1uF X7R 25V 10%; C_0805_2012Metric_Pad1.15x1.40mm_HandSolder; MPN 885012207078
C402, C403: 0.1uF X7R 25V 10%; C_0805_2012Metric_Pad1.15x1.40mm_HandSolder; MPN CL21B104KACNNNC
D401, D402, D403: BAT54S; SOT-23_Handsoldering; MPN TBAT54S,LM
J401, J402: Screw_Terminal_01x02; Term_Block_1x2_P5mm; MPN 1792863
Q401, Q402: SSM3K329R; SOT-23_Handsoldering; MPN SSM3K329R,LF
R401: 5.9K 0 .1%; R_0805_2012Metric_Pad1.15x1.40mm_HandSolder; MPN ERA-6AEB5901V
R402: 1K 0.1%; R_0805_2012Metric_Pad1.15x1.40mm_HandSolder; MPN ERA-6AEB102V
R403: 240 0.1%; R_0805_2012Metric_Pad1.15x1.40mm_HandSolder; MPN ERA-6AEB241V
R404: 41.2 0.1%; R_0805_2012Metric_Pad1.15x1.40mm_HandSolder; MPN 8-1625868-6
R405, R406, R408, R409, R413: 1K 1%; R_0805_2012Metric_Pad1.15x1.40mm_HandSolder; MPN RC0805FR-071KL
R407: 1.27K 1%; R_0805_2012Metric_Pad1.15x1.40mm_HandSolder; MPN RC0805FR-071K27L
R410: 1M 1%; R_0805_2012Metric_Pad1.15x1.40mm_HandSolder; MPN RC0805FR-071ML
R412: 1.15K 1%; R_0805_2012Metric_Pad1.15x1.40mm_HandSolder; MPN RC0805FR-071K15L
TP401: TP 1.25V; TestPoint_Pad_3.0x3.0mm
TP402: TP_Peak_Current; TestPoint_Pad_3.0x3.0mm
TP403: TP 1.395V; TestPoint_Pad_3.0x3.0mm
TR401: FS-10-110-C2; FS10-110-C2; MPN FS10-110-C2
U401: MIC7211YM5-TR; SOT-23-5_HandSoldering; MPN MIC7211YM5-TR
U402: LMC7101BYM5-TR; SOT-23-5_HandSoldering; MPN LMC7101BYM5-TR

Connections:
0: C401.2, C402.2, C403.2, D401.1, D402.1, R406.2, R410.2, R413.2, U401.5 (V-), U402.5 (V-); also elsewhere on the board
+3.0V: C402.1, D401.2, D402.2, R412.1, U401.2 (V+), U402.2 (V+); also elsewhere on the board
/+2.5V_REF: R405.1; also elsewhere on the board
/MainsPowerMonitor/AC_CurrentSense_N: C401.1, J402.2, Q402.3 (D), R402.2, R403.2, R405.2, R406.1, TP401.1, TR401.6, TR401.8
/MainsPowerMonitor/AC_Mains_Neutral: J401.2, TR401.4
/MainsPowerMonitor/AC_Mains_Phase: J401.1, TR401.1
/MainsPowerMonitor/Current_Range_Hi_Lo: Q401.1 (G), Q402.1 (G), R407.1, U401.1 (OUT); also elsewhere on the board
Mains_Current: D401.3, J402.1, R404.1, R409.1; also elsewhere on the board
Mains_Voltage: D402.3, R401.2, R402.1; also elsewhere on the board
unnamed: C403.1, D403.2, R408.1, R410.1, TP402.1, U402.4 (IN-)
unnamed: D403.3, U402.1 (OUT)
unnamed: Q401.2 (S), Q402.2 (S)
unnamed: Q401.3 (D), R403.1, R404.2
unnamed: R401.1, TR401.5, TR401.7
unnamed: R407.2, R408.2, U401.3 (IN+)
unnamed: R409.2, U402.3 (IN+)
unnamed: R412.2, R413.1, TP403.1, U401.4 (IN-)
unnamed: TR401.2, TR401.3

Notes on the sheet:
230V AC Nom 277V AC Max 392V Peak
5V AC Nom 8.5V Peak
1.25V
Current Sense Transformer 1:2000 60A = 0.03A
2.486V at Peak current
2.481V at 392V Mains
46:1
This transformer could be replaced with Ti's isolated precision amplifier: AMC1100 see slaa552.pdf
Note R405 and R406 put 1.25mA Load on ultimately on the 3.0V supply which is used to privide input protection to the micro. Without the load the voltage would just rise.
Vref = 1.395V
https://www.daycounter.com/Calculators/Comparator-Hysteresis-Calculator.phtml
VTH = 2.49V VTL=0.131V
Limit Over Rail voltage to 5mA
1.25V/281.2 = 4.44mA At Range Change = 8.89A on Primary Side
4.44mA X 41.2 = 0.183V After Range Change VTL must be below this to avoid oscillation I picked 0.131V

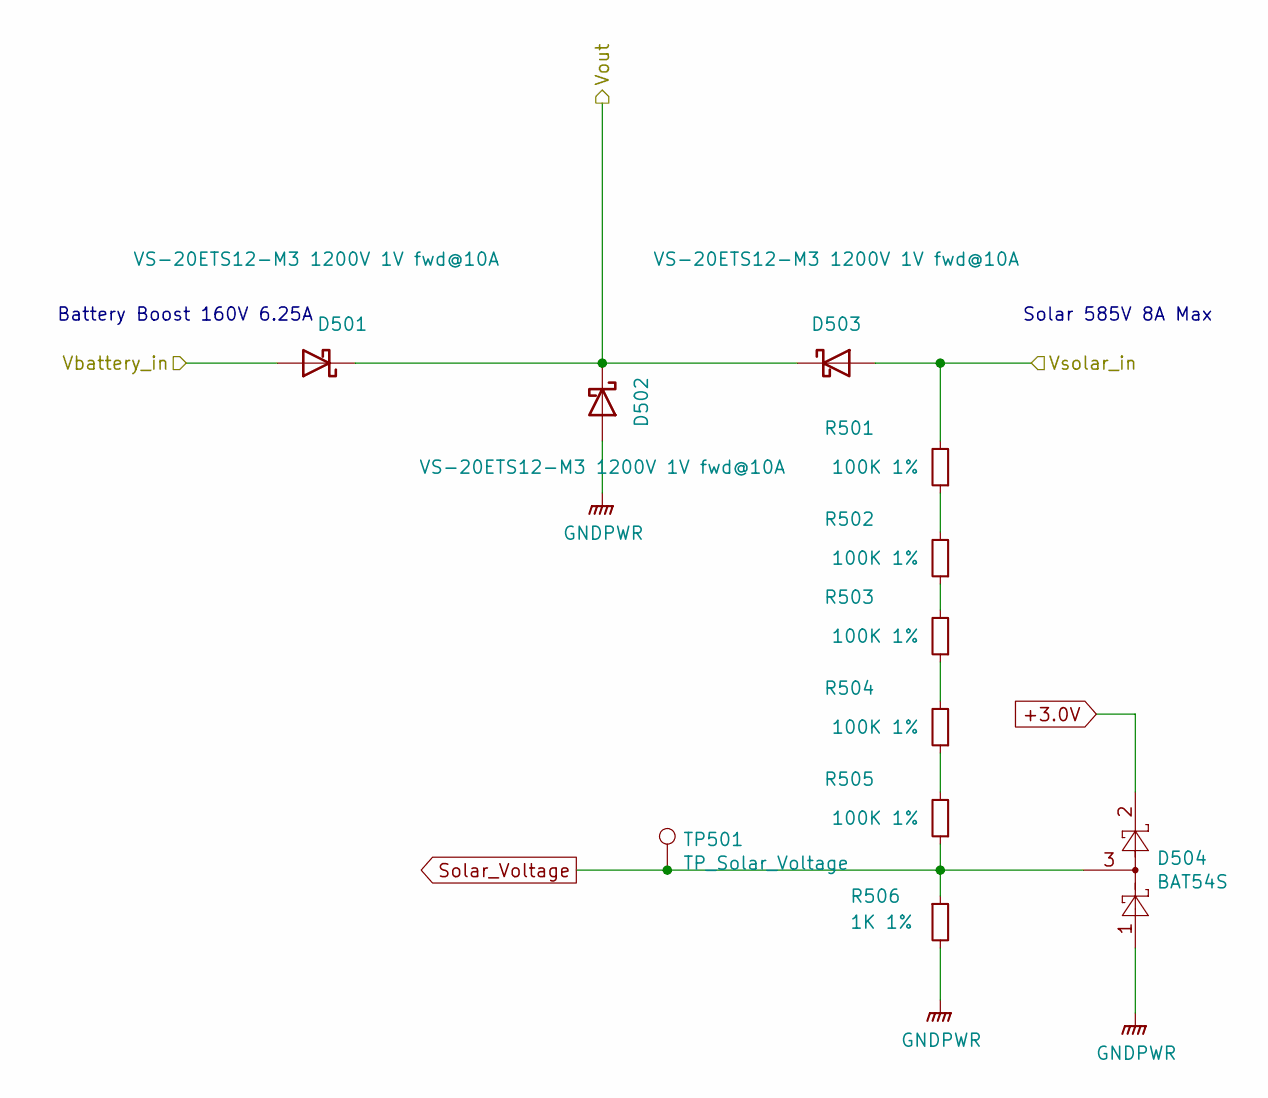
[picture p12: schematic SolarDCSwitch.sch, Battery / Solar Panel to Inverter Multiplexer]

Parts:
D501, D502, D503: VS-20ETS12-M3 1200V 1V fwd@10A; Diode_TO_220AC_Horizonal; MPN VS-20ETS12-M3
D504: BAT54S; SOT-23_Handsoldering; MPN TBAT54S,LM
R501, R502, R503, R504, R505: 100K 1%; R_0805_2012Metric_Pad1.15x1.40mm_HandSolder; MPN RC0805FR-07100KL
R506: 1K 1%; R_0805_2012Metric_Pad1.15x1.40mm_HandSolder; MPN RC0805FR-071KL
TP501: TP_Solar_Voltage; TestPoint_Pad_3.0x3.0mm

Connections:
0: D502.2 (A), D504.1, R506.2; also elsewhere on the board
+3.0V: D504.2; also elsewhere on the board
/Vout: D501.1 (K), D502.1 (K), D503.1 (K); also elsewhere on the board
/Vsolar_in: D503.2 (A), R501.2; also elsewhere on the board
unnamed: R501.1, R502.2
unnamed: R502.1, R503.2
unnamed: R503.1, R504.2
unnamed: R504.1, R505.2
Solar_Voltage: D504.3, R505.1, R506.1, TP501.1; also elsewhere on the board
Vboost_out: D501.2 (A); also elsewhere on the board

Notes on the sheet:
Solar 585V 8A Max
Battery Boost 160V 6.25A

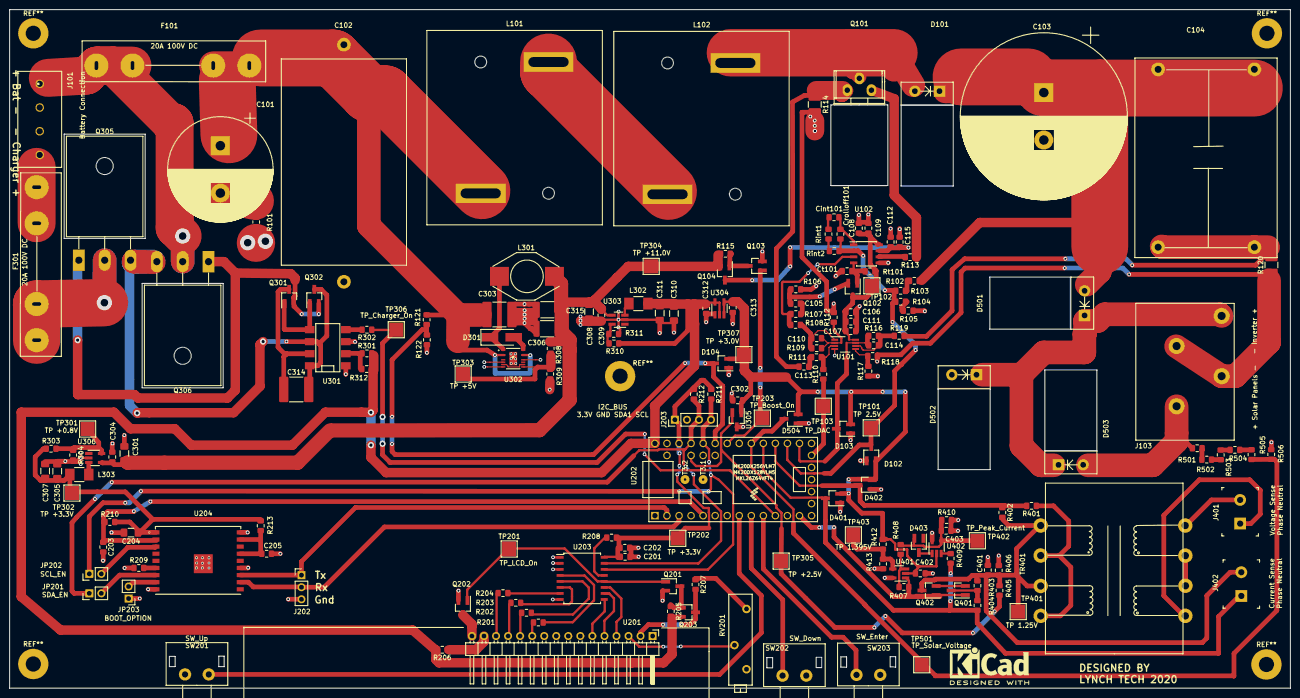
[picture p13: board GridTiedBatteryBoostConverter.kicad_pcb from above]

Board: 2 copper layers, 270.1 x 143.1 mm, 183 parts (0 on the bottom side), 111 nets.

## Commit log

2020-07-29 Inital commit of GridTiedBatteryBoostConverter, a bit off a mess but I should have a backupgit status
    [BatteryCellMeasurement.sch, GridTiedBatteryBoostConverter.csv, GridTiedBatteryBoostConverter.kicad_pcb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]
2020-07-30 started routing backing up tonnes of changes,2.048V reference changed to 2.5V ref, to match ucc2800, cos to change to a version with a 2V feedback, would require me to update the Oscillator cap and r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
    [GridTiedBatteryBoostConverter.kicad_pcb, GridTiedBatteryBoostConverter.sch, MainsPowerMonitor.sch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]
2020-07-31 Almost finished the routing, an other backup commit git add *
    [GridTiedBatteryBoostConverter.kicad_pcb, Teensy-LC.sch]
2020-07-31 Finish routing finally
    [GridTiedBatteryBoostConverter.kicad_pcb]
2020-07-31 fixed a few DRC errors, introduced error by adding edge.cuts to the buttons footprint, now warns board outline not complete. 3d wont completely render also because of this.
    [GridTiedBatteryBoostConverter.kicad_pcb]
2020-07-31 added mounting holes, should have done that sort of thing right at start.
    [GridTiedBatteryBoostConverter.kicad_pcb]
2020-07-31 added testpoints
    [GridTiedBatteryBoostConverter.kicad_pcb, GridTiedBatteryBoostConverter.sch, PowerSupplies.sch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]
2020-07-31 changed Buttons_Switches_ThroughHole_jl:SW_Tactile_SPST_Angled_FSM104 foot print
    [GridTiedBatteryBoostConverter.kicad_pcb]
2020-07-31 regenerated BOM, for the first time after new layout with wifi etc.
    [GridTiedBatteryBoostConverter.csv, GridTiedBatteryBoostConverter.kicad_pcb]
2020-08-01 Consolidated a lot of part values that were the same part but not detected the same by Boms_away BOM editor because of subtle differences in how I specified the values. Added Digi-key part numbers to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
    [GridTiedBatteryBoostConverter.kicad_pcb, GridTiedBatteryBoostConverter.sch, MainsPowerMonitor.sch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]
2020-08-02 change a few compoents foot prints for SOT23 to SOT23-Handsoldered, and SOT23-5 to SOT23-5-Handsoldered
    [GridTiedBatteryBoostConverter.kicad_pcb, GridTiedBatteryBoostConverter.sch, MainsPowerMonitor.sch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]
2020-08-02 Finished adding digi key part numbers, for now git add *
    [GridTiedBatteryBoostConverter.kicad_pcb, GridTiedBatteryBoostConverter.sch, MainsPowerMonitor.sch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]
2020-08-03 added thermal via of .3 drill size and .6, I have read the recomenned size is .25 drill but the smallest JLCPCB do for double sided boards is .3
    [GridTiedBatteryBoostConverter.kicad_pcb, GridTiedBatteryBoostConverter.sch, MainsPowerMonitor.sch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]
2020-08-03 regenerated built in kicad BOM Tool, since adding all the digi-key parts with bomsaway.py
    [GridTiedBatteryBoostConverter.csv]
2020-08-03 Generated BOM using bomsaway.py
    [BomsAway_GridTiedBatteryBoostConverter.csv]
2020-08-04 change Fuse details to a graphic note, and change the Fuse supply details to refer to the fuse holder, not the fuse it self. Also rerouted the charger input using 8mm trace width were possible.
    [GridTiedBatteryBoostConverter.kicad_pcb, GridTiedBatteryBoostConverter.sch, MainsPowerMonitor.sch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]
2020-08-04 added labels for the battery, charger, inverter and solar panels + - connections.
    [GridTiedBatteryBoostConverter.kicad_pcb]
2020-08-05 Started making progress towards people being able to clone the the repository without getting messages about missing librarys needing rescue. started simplifying where some component librarys are loc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
    [GridTiedBatteryBoostConverter.kicad_pcb, GridTiedBatteryBoostConverter.sch, MainsPowerMonitor.sch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]
2020-08-06 modified the symbol librarys and footprint librarys to use the project specific librarys instead of my global table making it easier for people to clone and use the project, with out missing librarie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
2020-08-06 Changed the ground plane copper fill zone to have a default clearance of 1.25mm to allow for up to 170V for external conductors uncoated according to IPC 2221B Table 6-1. Then the 500V connectors tra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
    [GridTiedBatteryBoostConverter.kicad_pcb]
2020-08-07 change how the current sense traces attach to the average output current sense resistor R120, they are now at right angles to the current sense resistor and attach directly to it.
    [GridTiedBatteryBoostConverter.kicad_pcb]
2020-08-07 further improved routing of sense trace to current sense resistor R120
    [GridTiedBatteryBoostConverter.kicad_pcb]
2020-08-08 Replaced TK32A12N1,S4X TO-220 Toshiba transistors that were use for turning the charger on and off, with a pair of IRFP4321PBF's from Infinion, in a TO-247AC package. The reson for the change was thi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
    [BomsAway_GridTiedBatteryBoostConverter.csv, GridTiedBatteryBoostConverter.csv, GridTiedBatteryBoostConverter.kicad_pcb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]
2020-08-08 Change footprint for the main switching FET to have a bent drain to achieve trace width and clearance requirements. Fixed a pin numbering miss alignment between schematic and footprint for the isolat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
    [GridTiedBatteryBoostConverter.kicad_pcb, GridTiedBatteryBoostConverter.sch, MainsPowerMonitor.sch]
2020-08-10 Improved clearance of Vin into U302 as good as the package will allow. Also reduced clearance around the Teesy to 0.5mm, because I notice one for the grounds was not connected.
    [GridTiedBatteryBoostConverter.kicad_pcb]
2020-08-11 The Wurth main inductors turned up today, and I spotted a stuff up with the footprint layout, pins are in the right spot, but the body outline is x-y switched, so the 2 inductors would not fit, so fi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
    [GridTiedBatteryBoostConverter.kicad_pcb]
2020-08-14 Found that my local updates of Kicad footprint librarys, had changed the names of resistor and capacitor footprints, so I updated all these footprint names. Added circuit to measure the Vin via pin 2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
    [BomsAway_GridTiedBatteryBoostConverter.csv, GridTiedBatteryBoostConverter.csv, GridTiedBatteryBoostConverter.kicad_pcb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]
2020-08-16 Added a dedicated fuse for the charger connection. Lowered the fuses from 25A to 20A after looking more closely at the data sheet. Charger is 19.5A atmost and Battery current draw at 80% efficency, 8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
    [GridTiedBatteryBoostConverter.kicad_pcb, GridTiedBatteryBoostConverter.sch, MainsPowerMonitor.sch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]
2020-08-17 Replaced the 3.5mm headphone jack which was used as the current transformer input, I thought due to the dangerous voltages that can be developed if it is connected to the mains without being pluged i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
    [GridTiedBatteryBoostConverter.csv, GridTiedBatteryBoostConverter.kicad_pcb, GridTiedBatteryBoostConverter.sch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]
2020-08-17 Added voltage divider network and input protection to measure, the Solar input voltage, I decided this would be usefull in the cases where the solar is producing voltage over 160V, but the house is s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
    [GridTiedBatteryBoostConverter.kicad_pcb, GridTiedBatteryBoostConverter.sch, PowerSupplies.sch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]
2020-08-17 Regenerated BOM after adding Solar Voltage measuring circuit, and updated TestPoint footprint that was missed in earler commit.
    [BomsAway_GridTiedBatteryBoostConverter.csv, GridTiedBatteryBoostConverter.csv, GridTiedBatteryBoostConverter.kicad_pcb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]
2020-08-22 Added Auto Range circuit to the Mains Current Sense, this will give close to 1W resolution on the mains measurment in the range 0-2000W vs about 6.6W resolution. Updated the BOM, which I think caused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
    [BomsAway_GridTiedBatteryBoostConverter.csv, GridTiedBatteryBoostConverter.csv, GridTiedBatteryBoostConverter.kicad_pcb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]
2020-08-22 Added Current_Range_Hi_Lo signal from the Mains Current Sense circuit to the Micro so we can tell what range we are operating on.
    [GridTiedBatteryBoostConverter.sch, MainsPowerMonitor.sch, PowerSupplies.sch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]
2020-08-22 Routed recent auto mains current ranging circuit.
    [GridTiedBatteryBoostConverter.kicad_pcb]
2020-08-23 Added extra FET in Current sense Auto Ranging circuit to stop the conduction of the body diode of the single FET on the negative half of the mains cycle. Also change the Values of all the TestPoints 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
    [BomsAway_GridTiedBatteryBoostConverter.csv, GridTiedBatteryBoostConverter.csv, GridTiedBatteryBoostConverter.kicad_pcb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]
2020-08-24 increased some trace sizes, moved some Front mask items, and generated the Gerber files, and submited order to jlcpcb, only order 1 oz copper but should be 2 oz due the the 20A charging part of the c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
    [BomsAway_GridTiedBatteryBoostConverter.csv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]
2021-02-19 added scope captures to diagnose lower power output ~11Watts.
    [boost_converter_gate_drive_and_cs_input_with_load.csv, boost_converter_gate_drive_and_cs_input_with_load_lower_DC_offset.csv, boost_converter_noload_gate_drive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]

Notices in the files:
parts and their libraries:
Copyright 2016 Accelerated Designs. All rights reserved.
